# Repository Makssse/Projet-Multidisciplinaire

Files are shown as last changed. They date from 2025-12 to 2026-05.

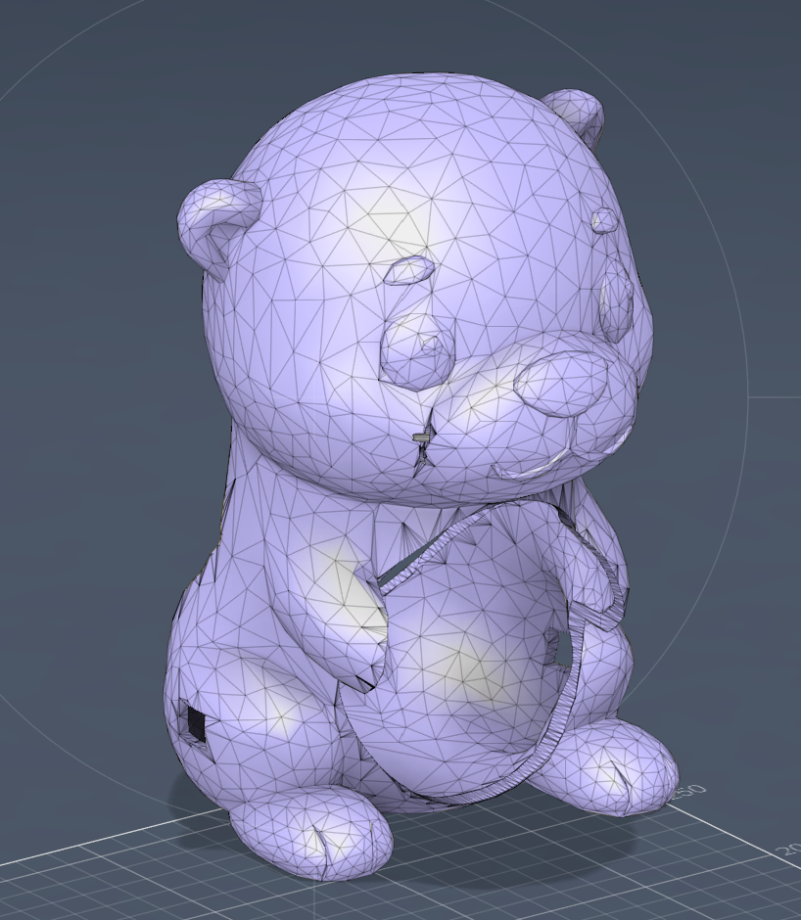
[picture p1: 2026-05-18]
impression_3d/Fichiers pour impression/Loutre VF.png

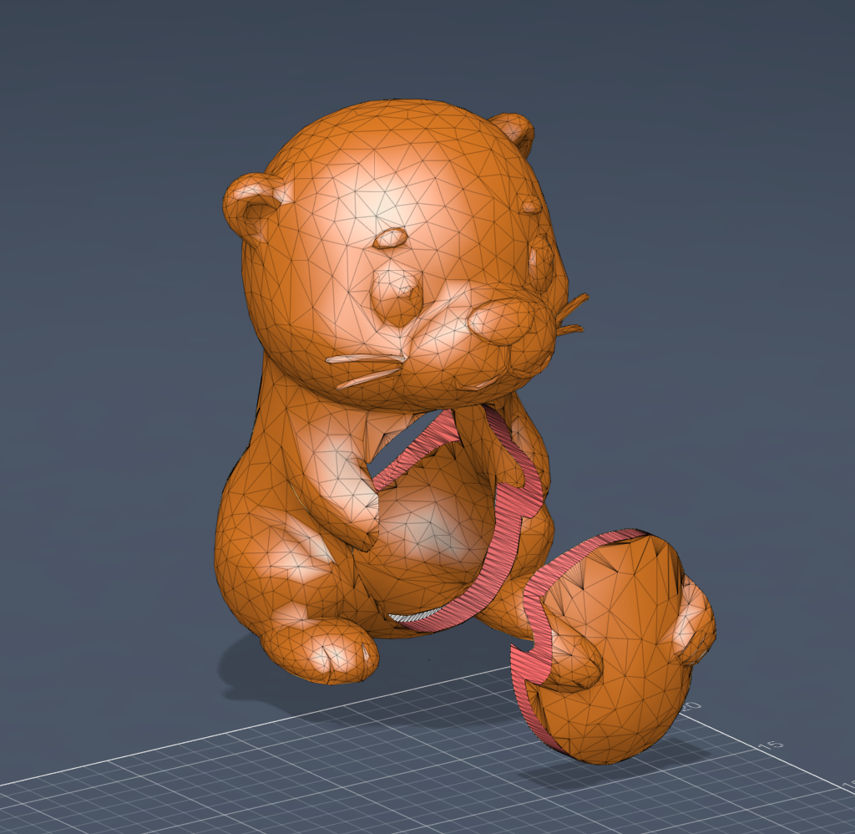
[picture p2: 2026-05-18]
impression_3d/Fichiers pour impression/Loutre et ventre.png

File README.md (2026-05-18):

# Projet-Multidisciplinaire
Nous sommes des étudiants en Génie Physique à l'INSA Toulouse et travaillons sur un projet de réseau de capteurs C02 pour des bâtiments publics (écoles, mairies...). Nous avons crée ce GitHub dans le but de rendre ce projet accessible à tous.tes, notamment aux non-intié.e.s qui souhaiteraient l'implémenter dans leurs locaux.

Vous pouvez y trouver : 
- le "Guide de fabrication" qui est un manuel de construction contenant tous les détails nécessaires à la fabrication des capteurs et à la mise en place du réseau. Ce manuel indique dans chaque section quand se servir des autres ressources du Github.
- le dossier "Home Assistant" qui contient tout les codes nécessaire à la création de l'interface utilisateur.
- le dossier "src" qui contient tout le code python et notament :
    - les codes à implémenter sur les pi pico (dossiers "code salle x")
    - le code pour tester son réseau ethernet dans le dossier "test_ethernet" (le protocole de test est disponible dans la section test ethernet du manuel de fabrication)
    - les codes de test pour chaque composante et capteurs dans le dossier "code test"
    - les autres code qui nous ont été utile dans le dossier "autre code"
- le dossier initialisation RP Pico qui contient le fichier d'initialisation de la Pi Pico. Vous trouverez le protocole dans le guide d'utilisation.
- le dossier "impression 3D" ou vous trouverez tous les fichiers nécessaire à l'impression de la coque 3D dans un fablab, les fichiers à imprimés étant dans le dossier "fichiers pour impression" : "LOUTRE_CREUSEE_VF" et  "LOUTRE_VENTRE_VF".
- le dossier "rendus INSA" avec touts les documents que nous avons du produire et rendre pour lors de ce projet à nos enseignant.es.

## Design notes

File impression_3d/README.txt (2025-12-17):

Mini Otter by AR3DP on Thingiverse: https://www.thingiverse.com/thing:7198225

Summary:
If you enjoy my designs and would like to support my work, or get a commercial license to sell prints of my models — you can join me on Patreon: 👉 https://www.patreon.com/cw/AR3DPI’ll be gradually adding colored profiles for the Mini Zoo collection on my Patreon.This model depicts a playful otter interpreted in the Mini Zoo style, featuring rounded shapes, soft transitions, and a friendly upright pose that emphasizes its curious and gentle demeanor. The low-poly treatment of the body and tail provides structure while maintaining the charm of a compact collectible.The Mini Otter embodies curiosity and playfulness, making it a lively addition to the Mini Zoo’s aquatic category. It complements models like the penguin and seal, representing an important balance between land and water creatures within the collection.Recommended material: PLA+ or PETG for smooth surfaces and durability. Use a medium brown for the body and a lighter cream tone for the chest and muzzle. A 0.16 mm layer height is ideal for capturing the subtle contouring of the face.A little message:Your support helps me keep creating and improving new designs every day. Don’t forget to follow, like, and favorite the models you enjoy, it truly helps and motivates me to keep exploring new ideas and sharing more creations. And please share photos of your printed versions, it’s always exciting to see how each person brings their own style and creativity to life! Thank you for being part of this journey!

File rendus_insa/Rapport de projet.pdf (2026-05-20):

# Rapport de projet

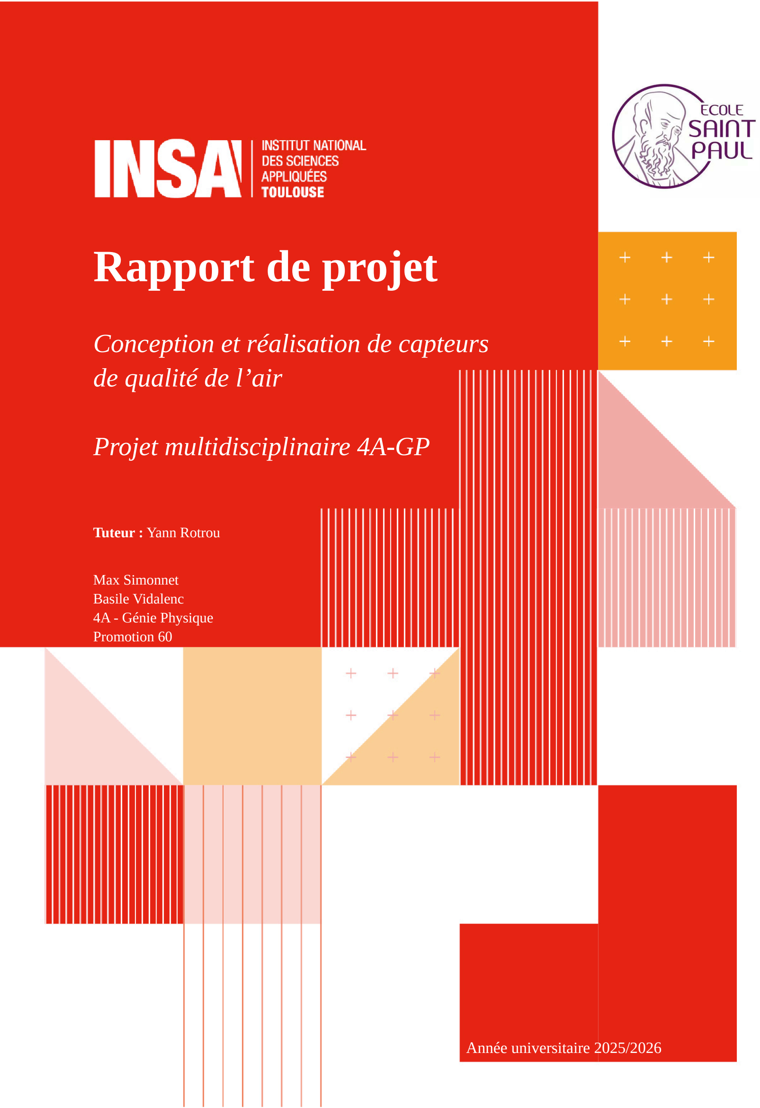
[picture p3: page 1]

## Conception et réalisation de capteurs de qualité de l’air

## Projet multidisciplinaire 4A-GP

Tuteur : Yann Rotrou

Max Simonnet
Basile Vidalenc
4A - Génie Physique
Promotion 60

Année universitaire 2025/2026

## 1. Résumé

Ce projet est un projet de conception et de réalisation d’un réseau de capteurs de qualité de l’air intérieur (QAI) pour un établissement scolaire. L’école Saint Paul, dans laquelle prend place notre projet, avait déjà réalisé une session d’auto-évaluation QAI avec des capteurs commerciaux. Elle n’a cependant pas retrouvé dans ces capteurs deux fonctionnalités qui lui sont nécessaires : l’affichage ludique d’un statut instantané et l’acquisition des données de façon permanente. De plus, ces capteurs présentent un coût élevé (120€ pièce pour un capteur NetAtmo).

Ainsi, dans notre projet, chaque capteur, placé dans un boîtier de mesure, mesure la qualité de l’air (CO2), la température, l’humidité relative et le volume sonore relatif et donne des indications en temps réel et permettant au enseignant.e.s de savoir quand il faut aérer la salle, et aux élèves d’être sensibilisé.e.s. L’acquisition des données se fait ensuite sur une centrale d’acquisition, permettant ainsi des analyses et la mise en place d’actions plus long terme.

## 2. Remerciements

Tout d’abord, un merci infini à notre tuteur, M. Yann Rotrou. Yann, tu as été une très belle rencontre tant sur le plan humain que sur le plan professionnel cette année. Tu as toujours été à l’écoute et bienveillant lorsque nous étions au point mort. Tu nous as fait confiance en nous laissant une grande autonomie, toujours partant pour chacune de nos idées sans jamais nous pressuriser tout en nous guidant sur les éventuelles difficultés que nous pouvions rencontrer. Un immense merci à toi pour ce projet et cette année !

Ensuite, nous tenions à remercier chaudement M. Jérémie Grisolia, dont l’expertise nous a fait gagner un temps précieux dans la recherche des composants, du protocole de communication adapté et de la bonne interface graphique. Jérémie, la porte de ton bureau était toujours ouverte quand nous avions des questions, des points de blocage, des erreurs… et le tout avec une gentillesse extrême. Merci à toi pour tout cela !

De même, un grand merci à Cathy avec qui nous avons conceptualisé et produit une première ébauche de PCB pour acquérir le signal du capteur. Merci à toi pour ta patience et ton absence de jugement sur nos compétences parfois douteuses en électronique.

Sur le plan organisationnel, nous remercions Lise Arnould, dont l’efficacité et la rapidité extrême nous ont permis d’aller en personne mettre en place le projet au sein même de l’école dans les meilleures conditions.

Un immense merci au Fablab de l’INSA et à ses bénévoles, qui ont passé des heures avec nous pour peaufiner nos design afin de les rendre imprimable en 3D dans les meilleures conditions.

Enfin, merci au CSN et notamment à Louis Chanouha, qui nous a ouvert un sous-réseau au GP.

Merci aussi à tout.es celleux qui ont pu nourrir ce projet en mettant à disposition en ligne des ressources Open Source. La majorité de notre code, notre design 3D, et toutes les connaissances que nous avons acquises : nous les devons à ces personnes. Nous espérons que notre projet pourra un jour inspirer ou aider quelqu’un à son tour.

## 3. Table des matières

## 4. Contexte

Ce projet s’inscrit dans notre 4ème année de formation à l’INSA Toulouse dans la spécialité Génie Physique. Nous sommes donc deux étudiants et notre tuteur Yann Rotrou est ingénieur en instrumentation chez Safran. Il est également impliqué dans la vie administrative et associative de l’école Saint Paul de Cesson en tant qu’administrateur OGEC (Organisme de Gestion des Ecoles Catholiques). A ce titre, il siège au Conseil d’Administration de l’école et participe donc aux décisions en terme de d’organisation, de finance et de fonctionnement de l’école. Pour l’école Saint Paul, ce projet fait suite à la campagne d’auto évaluation de 2024, et fait partie du plan d’action présenté dans son rapport. Il repose sur le constat qu’il n’existe pas de capteur commerciaux respectant le besoin d’un affichage ludique, d’une centralisation des données et d’un faible coût, correspondant aux capacités économique d’un établissement scolaire.

### 4.1 Contexte réglementaire

La conception et l’installation de capteurs de qualité de l’air intérieur dans un établissement scolaire doivent respecter plusieurs normes et recommandations, tant au niveau national qu’international. En France¹, la réglementation encadrant la qualité de l’air dans les établissements recevant du public (ERP) repose sur le Code de la santé publique et des recommandations du Ministère de la Transition écologique et de la Santé, qui définissent notamment des seuils d’exposition² pour les polluants atmosphériques (particules fines PM2,5 et PM10, dioxyde de carbone, composés organiques volatils, etc.), ainsi que pour le confort thermique et l’humidité intérieure. Concernant le bruit, les normes françaises (NF S31-080 et NF EN ISO 3382) fixent des limites d’exposition³ dans les espaces publics et scolaires afin de préserver l’audition et le confort des élèves et du personnel.

### 4.2 Contexte sanitaire

Au niveau international, l’Organisation mondiale de la Santé (OMS) fournit des recommandations visant à protéger la santé des enfants et des adolescents. L’OMS établit des valeurs guides pour les concentrations de polluants atmosphériques dans les espaces intérieurs, notamment :

- Particules fines (PM2,5) : concentration annuelle moyenne inférieure à 5 µg/m³.
- Particules fines (PM10) : concentration annuelle moyenne inférieure à 15 µg/m³.
- Dioxyde de carbone (CO₂) : concentration inférieure à 800 ppm pour garantir une ventilation adéquate et maintenir la concentration et la vigilance.
- Température intérieure : plage recommandée entre 18 et 22 °C pour assurer le confort thermique.
- Humidité relative : plage recommandée entre 30 % et 60 % pour prévenir les risques de moisissures et garantir le confort.

¹Arrêté du 27 décembre 2022 fixant les conditions de réalisation de la mesure à lecture directe de la concentration en dioxyde de carbone dans l’air intérieur au titre de l’évaluation annuelle des moyens d’aération (Légifrance)
²Tableau des normes Qualité de l’Air (ecologie.gouv.fr)
³Arrêté du 25 avril 2003 relatif à la limitation du bruit dans les établissements d’enseignement (Légifrance)

- Niveau sonore : niveau sonore inférieur à 35 dB(A) pour favoriser la concentration et l’apprentissage.

## 5. Présentation générale du projet

### 5.1 Le Github

Tout notre projet est disponible en open source sur Github. Vous pouvez y trouver tous les fichiers utilisé, les codes sources et un guide de fabrication et d’utilisation qui permet de refaire chez soi le réseau de capteurs. Tout notre code est donc disponible à cette adresse : https://github.com/Makssse/Projet-Multidisciplinaire

### 5.2 Contraintes

Pour réaliser ce projet nous nous sommes basé sur un cahier des charge fournit par notre tuteur. Il est résumé ci-dessous les principales contraintes et objectifs présent dans ce cahier.

### 5.2.1 Au niveau du boîtier de mesures

1. Chaque boîtier ludique doit admettre au minimum un capteur de taux de CO2 et un capteur de température.
2. Le capteur de taux de CO2 doit reposer sur la technologie NDIR.
3. L’aspect visuel du boîtier doit être ludique. Il pourra être discuté avec la directrice de l’établissement.
4. Le boîtier doit visuellement présenter un voyant vert lorsque le taux de CO2 est inférieur à 800ppm, orange lorsque le taux de CO2 dépasse le 800ppm, et rouge lorsque le taux dépasse 1500ppm. Cela permettra d’ouvrir la fenêtre quand besoin. En optionnel, ces seuils doivent pouvoir être modifiés sur la centrale d’acquisition, pour tous les capteurs.
5. La couleur doit être visible à quelques mètres, pour l’ensemble des élèves de la classe.
6. Les boîtiers doivent être alimentés sur le secteur, ou équipés de batteries ayant une autonomie supérieure à 6 mois.

### 5.2.2 Au niveau du système d’acquisition/gestion

7. Possibilité de définir des heures de présence (par défaut, identiques pour toutes les pièces, à l’échelle de la semaine. En option : configurable pour chaque pièce).
8. Sur les heures de présence, sauvegarde de toutes les grandeurs physiques mesurées toutes les 10 minutes, et enregistrement centralisé. Le matériel et le protocole de communication sont à discuter⁴.
9. Les boîtiers sont identifiables et on peut leur attribuer sur l’interface un nom facilement modifiable à la journée.
10. Afin de pouvoir maintenir ou remplacer le matériel, toutes les informations nécessaires sont fournies : plan des boîtiers, code source et description de l’installation de l’interface centrale.

⁴après discussions avec notre tuteur et l’école, l’idée d’un système filaire fut privilégiée

### 5.3 Description et fonctionnement final

Le système final (Figure 1) est donc composé de boîtiers d’acquisitions qui :
- Pilotent des LED qui changent de couleurs selon le niveau de CO2 (vert < 800ppm : orange < 1500ppm ; rouge > 1500ppm) en continue.
- Envoient des données toutes les 10min via Ethernet.

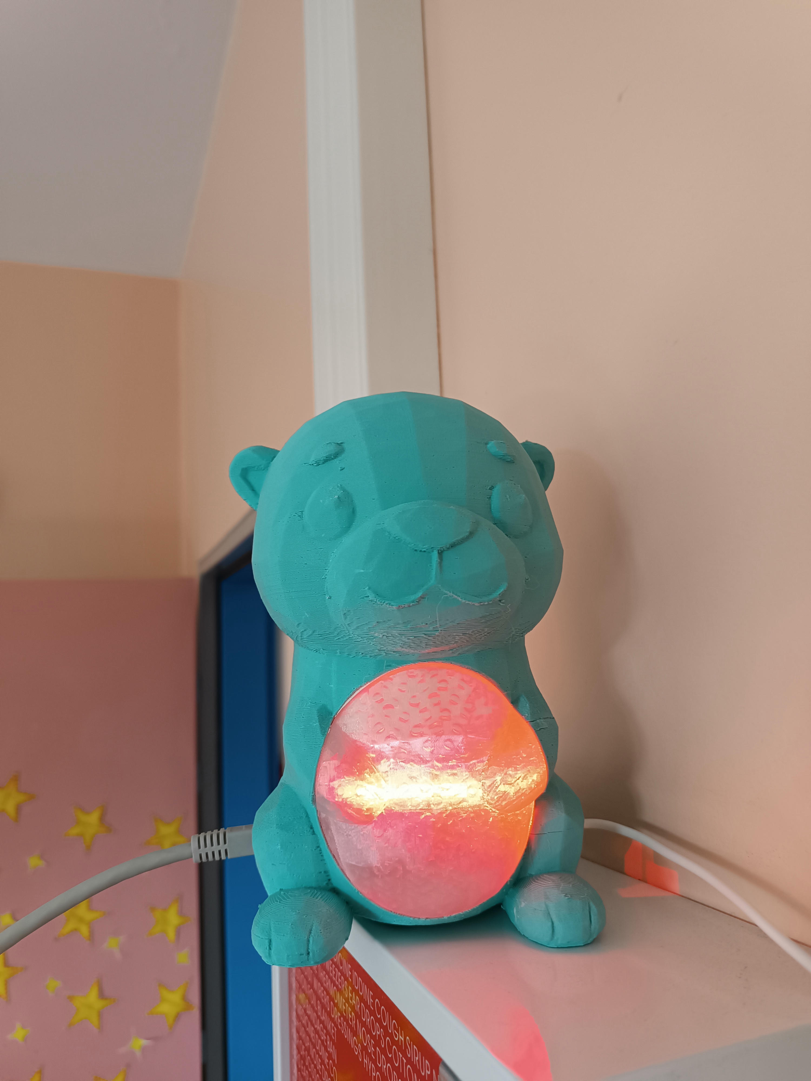
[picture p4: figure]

Fig. 1. – Photo de notre loutre en fonctionnement avec un taux de CO2>1500ppm.

Chaque boîtier de capteur est composé d’une coque imprimée en 3D, d’une Raspberry Pi Pico, d’un capteur Groove Loundness Sensor (en bas de la Figure 2), d’un capteur SCD 40 (petit boitier en haut de la Figure 2), de LED adressables et de toute la connectique nécessaire (shield Pi Pico, câble Ethernet et alimentation).

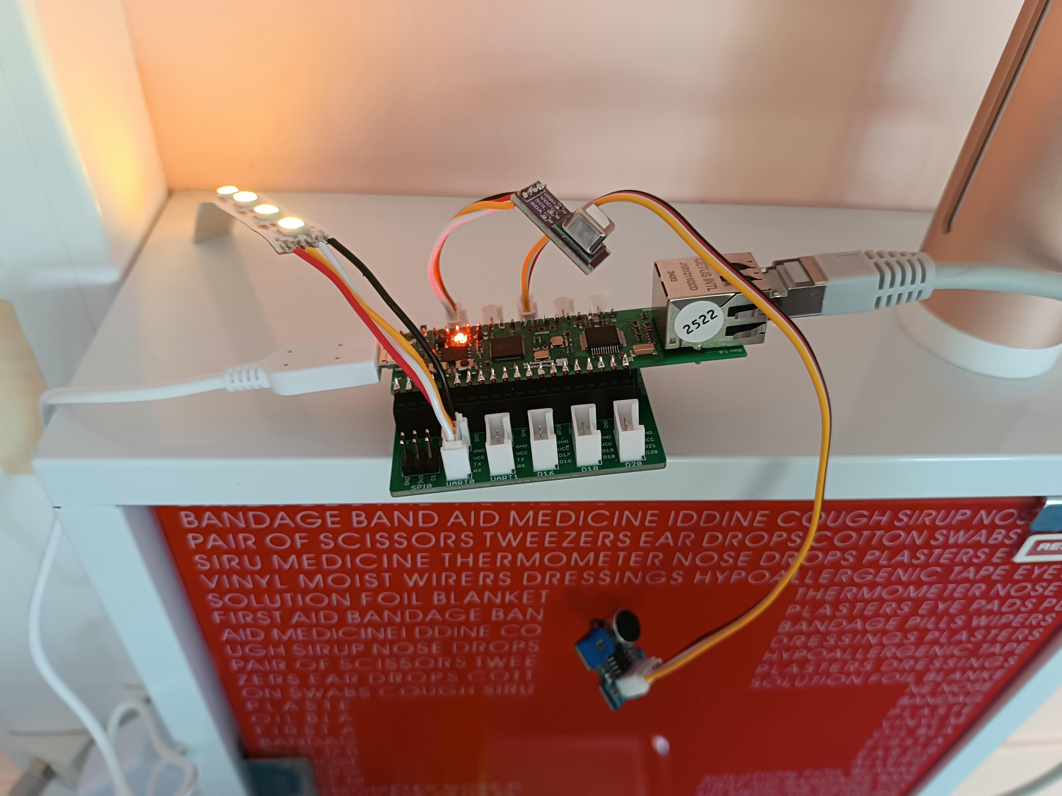
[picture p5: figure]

Fig. 2. – Photo du la Pi Pico et de ses composantes, destinés à aller dans la loutre de la Figure 1.

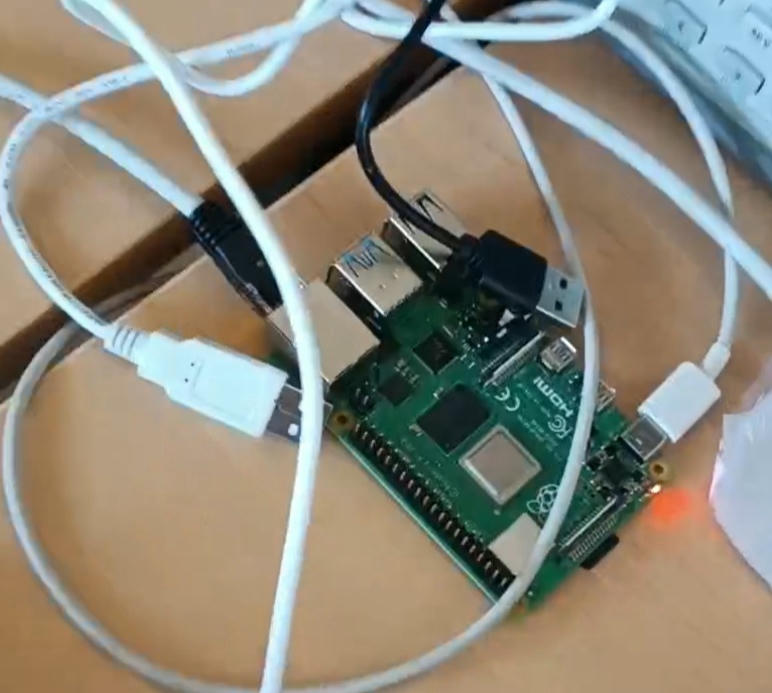
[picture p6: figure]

Fig. 3. – Photo de la Raspberry Pi 4, connecté à Ethernet.

Une Raspberry Pi 4 (Figure 3) reçoit ensuite toute la donnée Ethernet et permet d’afficher sur un ordinateur relié au réseau une interface utilisateur Home Assistant qui permet :
- De voir en direct et sur différentes échelles de temps les données pour chaque capteur.
- D’arrêter ou de mettre en marche les capteurs de manière collective ou individuelle, et de manière manuelle ou automatique (en définissant des heures/jours de présence).
- D’effectuer des re-calibrations pour la température et le taux de CO2 pour chaque capteur.
- D’envoyer des rapports automatiques via Telegram.
- De calculer et d’afficher l’indice ICONE (un indice sur la QAI) pour chaque salle en pouvant choisir l’échelle de temps sur laquelle l’indice est calculé.

Nous allons revenir dans la partie suivante plus en détail sur le fonctionnement global, sur le rôle de chaque composante du projet et sur le travail effectué.

## 6. Travail réalisé

### 6.1 Choix des composants

Nous avons choisi les composants en début de projet afin qu’ils correspondent au cahier des charges tout particulièrement sur les aspects :
- ludique (pour le boîtier de mesure qui sera dans les salles)
- d’accessibilité et de reproductibilité (pour que tout un chacun puisse recréer le projet chez lui)
- de conformité aux normes de mesure CO2 (technologie NDIR)

Pour plus d’informations sur ce qui a motivé nos choix, se référer à la ScoreCard présente en Annexe (Chapitre 8.1).

### 6.1.1 Le capteur de CO2 : SCD40

Le SCD40 de chez Sensirion est un capteur de CO2, Température et Humidité relative. Il utilise la technologie NDIR pour la mesure de CO2, qui est la technologie fixée par la norme française pour la mesure de CO2 dans les écoles.

La communication se fait via I2C. Le capteur possède 2 pins d’alimentation (V+ et GND) ainsi qu’une pin SDA pour les données et une pin SCL pour l’horloge. Sensirion a développé une bibliothèque Python que nous avons utilisé pour communiquer avec notre capteur et implémenter les fonctions utiles (plus d’info au Chapitre 6.4.1).

### 6.1.2 Le microcontrôleur : Raspberry Pi Pico W5500-ETH

Afin d’être parfaitement autonome dans le boîtier de capteur, il est nécessaire de se doter d’un microcontrôleur qui aura pour rôle de communiquer avec les différents modules que nous y branchons : le SCD40 (CO2), le Loudness Sensor (bruit), les LEDs (indication visuelle) et l’Ethernet.
Pour ce faire, nous avons choisi la Raspberry Pi Pico-W5500-ETH, qui rajoute un module Ethernet fixe à la Pi Pico de base. Ce microcontrôleur dispose des caractéristiques suffisantes à la mise en place de notre projet en terme de mémoire (264kB SRAM, 2MB Flash), de capacité de calcul (133MHz Dual-core) et de communication puisqu’il dispose de Pins I2C, digitaux (I/
O) et analogues.

### 6.1.3 La centrale d’acquisition : Raspberry Pi 4B+

Le choix de la centrale a été fait en même temps que le choix du logiciel pour l’acquisition et le traitement de données, et l’interface graphique. Nous avons décidé de partir sur Home Assistant OS puisque l’école fonctionnait déjà dessus avec une Raspberry Pi 4B+ pour ses capteurs commerciaux. Ainsi, étant déjà lancés dans la suite Raspberry, nous avons décidé de choisir une Pi4B+ également. La Raspberry Pi 4 est compatible avec Home Assistant et possède des caractéristiques suffisantes en terme de stockage (32GB) et de RAM (2GB minimum).

### 6.1.4 L’indication visuelle : les LEDs adressables

Les LEDs adressables sont un bon outil pour maîtriser l’information visuelle que l’ont veut donner. Ces LEDs peuvent être adressées puis contrôlées individuellement via les Pins DT (DATA) et CLK (CLOCK), en étant alimentées via les Pins V+ (tension d’alimentation) et GND (masse) (plus d’info au Chapitre 6.4.1).

### 6.2 La coque 3D

Pour réaliser la forme du boîtier de capteur qui sera présent dans les salles de classe, nous nous sommes basés sur ce modèle⁵ (https://www.thingiverse.com/thing:7198225) de loutre, crée par AR3DP.

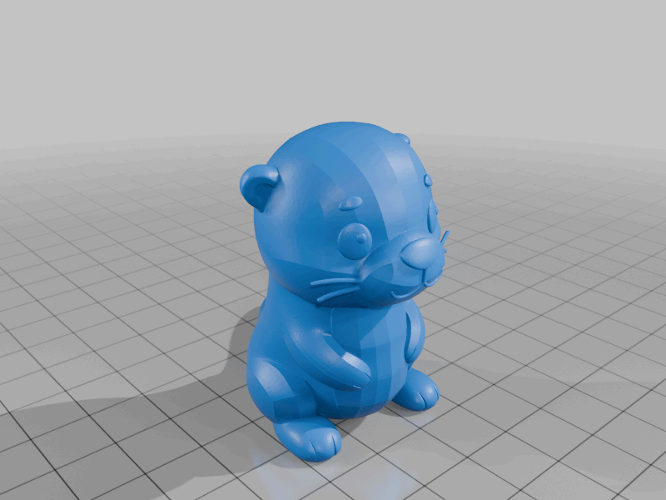
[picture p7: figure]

Fig. 4. – Modèle initial du boîtier (créateur : AR3DP)

Ce modèle est sous licence CC BY-NC 4.0 qui nous permet de le modifier et de le partager gratuitement, en citant l’auteur.

A l’aide de l’outil Meshmixer, nous avons creusé l’intérieur de la loutre pour ensuite extruder l’avant et l’arrière sur Fusion 360. Le trou à l’arrière sert à placer le capteur dans la loutre, et celui à l’avant à placer un ventre transparent qui permet de diffuser la lumière produite par les LEDs. Enfin, 2 trous rectangulaires ont été placés sur les côtés de la loutre afin de faire passer les câbles USB et Ethernet, nécessaires respectivement à l’alimentation et à la connexion au réseau. L’impression en fabrication additive a été faite au FabLab de l’INSA, en PETG bleu cyan pour la loutre et en PETG transparent pour le ventre.

⁵https://www.thingiverse.com/thing:7198225

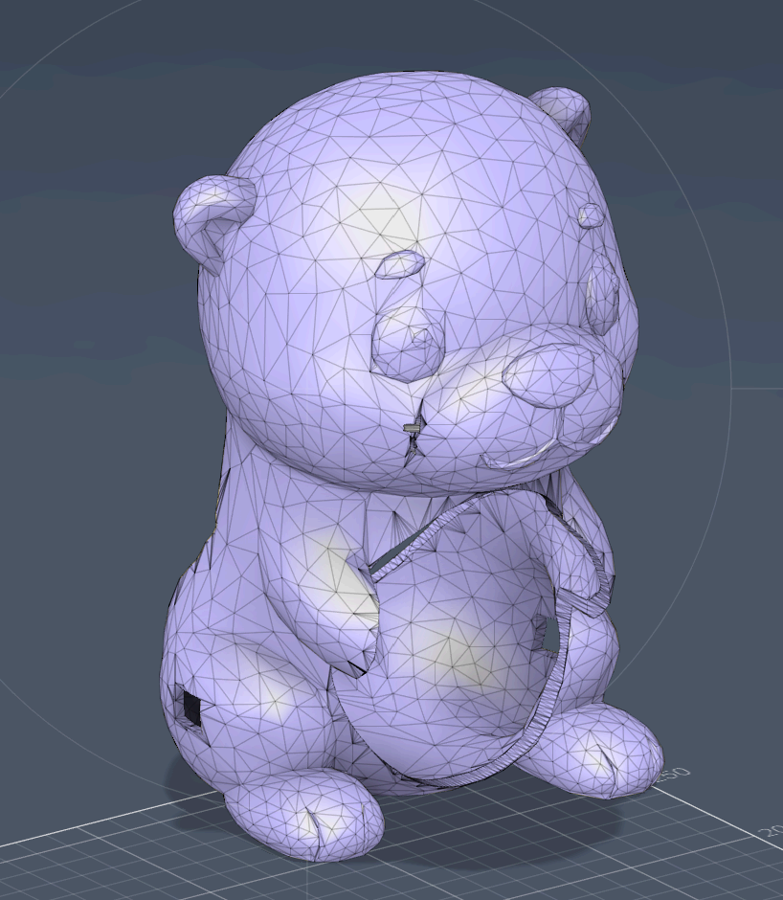
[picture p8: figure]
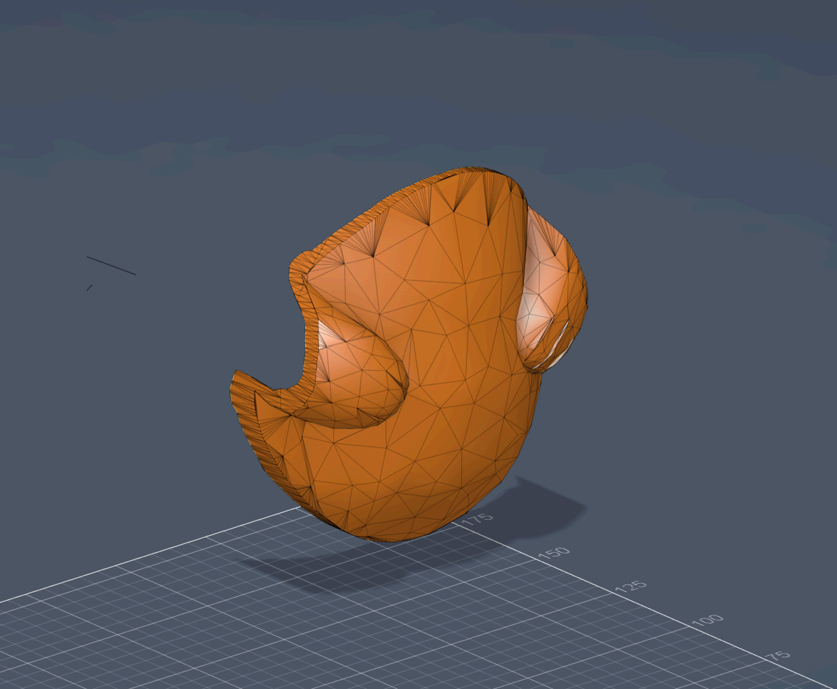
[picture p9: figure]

Fig. 5. – Loutre et ventre, fichier prêt pour impression (.stl)

### 6.3 La mise en place réseau

### 6.3.1 Communication MQTT

Pour assurer la communication entre les boîtiers de capteurs et la centrale d’acquisition, nous avons choisi le protocole MQTT (Message Queuing Telemetry Transport). Ce protocole repose sur un modèle « publish/subscribe » : chaque Pi Pico publie ses données sur un « topic » (un canal de communication identifié par une chaîne de caractères), et la Raspberry Pi 4 qui fait tourner Home Assistant s’abonne à ces topics pour récupérer les données en temps réel. Un broker Mosquitto, installé sur la Pi 4, joue le rôle d’intermédiaire central et redistribue chaque message à tous les abonnés concernés.

Nous avons fait le choix d’implémenter nous-mêmes la couche MQTT dans notre bibliothèque lib_mqtt.py plutôt que d’en utiliser une existante, afin de garder un code léger et adapté aux contraintes mémoire de la Pi Pico. Concrètement, à chaque démarrage, la Pi Pico établit une connexion TCP avec le broker en lui envoyant un paquet CONNECT contenant son identifiant, ses identifiants de connexion et un testament (will_topic()). Ce dernier permet au broker de publier automatiquement un message offline si le capteur venait à se déconnecter brutalement, ce qui permet à Home Assistant de détecter une panne.

Une fois connectée, la Pi Pico fonctionne dans les deux sens. D’un côté, elle publie toutes les 10 minutes ses mesures (CO₂, température, humidité, bruit) au format JSON sur son topic dédié. De l’autre, elle est abonnée à un topic de commande "/set_status" sur lequel Home Assistant peut envoyer des ordres : allumer ou éteindre le système, modifier l’offset de température, changer les seuils d’alerte CO₂, ou encore forcer une recalibration du SCD40. Ces messages entrants sont traités par la fonction reception_message() du main, qui est une fonction de rappel (callback) et s’exécute automatiquement dès qu’un message arrive. En effet, check_msg() ne déclenche automatiquement reception_message() que lorsque qu’elle détecte un message, afin de ne jamais bloquer le programme.

### 6.3.2 Tests sur l’INSA

Avec l’aide du CSN, nous avons mis en place un sous-réseau de test en salle d’instrumentation
2.15. Ce sous-réseau nous a permis de mimer un réseau local régit par une box, ce qui se rapproche le plus de l’architecture réseau de l’école (peu de hiérarchie réseau/sous-réseau, ce qui facilite la communication entre ports). Ce sous-réseau contenait 4 ports Ethernet reliés entre eux et permettant de brancher :
- 1 Raspberry Pi 4 (centrale d’acquisition/Execution de Home Assistant),
- 1 PC (accès à Home Assistant)
- 2 Raspberry Pi Pico (mesure/indication visuelle/envoi de données à la centrale)

A l’aide de ce sous-réseau nous avons pu :
- créer l’interface utilisateur sur Home Assistant et d’implémenter des codes .yaml correspondant aux exigences de l’école via le PC (voir Chapitre 6.5.1)
- vérifier la robustesse de notre couche MQTT (créée par un code python) : envoi et réception de message sur la Pi Pico et sur Home Assistant.
- identifier les points critiques qui pourraient poser problème lors de la mise en place à l’école :
- l’IP du Broker MQTT (i.e. de la Pi 4), essentielle à connaître et à indiquer dans le main.py des Pico afin de pouvoir communiquer
- l’IP de la passerelle, du masque de sous-réseau et du DNS, à indiquer dans lib_mqtt.py

### 6.3.3 Mise en place à l’école

Lors de la mise en place du réseau, basée sur la « Feuille de route mise en place du réseau » présente sur notre GitHub, nous avons suivi les étapes suivantes afin de tester la communication MQTT :
- récupération des IPs utiles (passerelle, masque de sous-réseau, DNS) et implémentation dans notre code
- fixation de l’IP de la Pi 4 (donc du Broker MQTT) et implémentation dans notre code
- connexion au Home Assistant via un PC connecté au réseau
- test de tous les ports Ethernets de l’école et vérification qu’ils sont sur le même réseau
- test final en faisant tourner notre code

Mis à part un problème de temps d’attente de connexion au réseau pour les Pi Pico dans certaines salles (voir Chapitre 7.2.2), la mise en place s’est déroulée sans accrocs.

### 6.4 Le code de la Pi Pico

Nous allons dans cette section aborder le code implémenté sur la Raspberry Pi Pico que nous avons créé et testé sur l’environnement VS Code. Ce code permet 2 choses :
- De fonctionner de manière autonome et d’indiquer grâce à la bande LED le taux de CO2.
- De recevoir et d’envoyer des messages via MQTT.

Nous n’allons pas aborder tous les codes réalisés, il y a notamment en plus sur le Github des codes de tests des différents composants et du réseau Ethernet. Dans cette section nous allons dans une première partie revenir sur les différentes librairies que nous avons créées, puis sur le code principal dans une seconde partie.

### 6.4.1 Nos différentes bibliothèques

- lib_Led.py :

Cette bibliothèque se base sur une bibliothèque récupérée depuis un Github de pilotage python des LED WS2812B. On y retrouve la fonction config_led() qui permet d’initialiser les LEDs en passant en argument le nombre de LED, l’intensité voulue et les pins sur lesquelles elles sont connectées. La fonction indicateur_visuel() qui permet de changer la couleur du bandeau LED en passant en argument le taux actuel de CO2. La dernière fonction est piloter_led() qui permet d’allumer complètement (lumière blanche) ou d’éteindre le bandeau LED.

- lib_son.py :

Cette librairie permet d’utiliser le Grouve Loundness Sensor.
On y trouve la fonction config_port_son() qui initialise le capteur en passant en argument la pin sur laquelle il est connecté. La deuxième fonction est niveau_sonore() qui renvoie une valeur brute du niveau sonore comprise entre 0 et 65535.
- lib_scd4x.py :

Cette bibliothèque se base sur une bibliothèque récupérée depuis le Github officiel du SCD40 ainsi que sur une bibliothèque Adafruit. Elle permet de contrôler le SCD40.
On y retrouve la fonction config_port_scd() qui permet de définir les pins SDA et SCL. La fonction obtenir_donnees() qui renvoie le taux de CO2, la température et l’humidité relative. Enfin deux fonctions permettent de modifier les paramètres de fonctionnement du SCD40. change_parametres() permet de mettre à jour l’offset de température (que l’on doit corriger pour prendre en compte l’échauffement du capteur) et l’altitude de fonctionnement. recalibration() permet de forcer une calibration sur un niveau de CO2 connu. Sinon le SCD40 effectue une calibration automatique toutes les semaines en se basant sur les valeurs les plus basses rencontrées.
- lib_mqtt.py :

Cette bibliothèque contient la class MQTTClient que l’on doit initialiser en donnant les informations de notre broker (ici relatives à la Pi 4).
On y retrouve la fonction connecter_ethernet() qui permet de configurer la connexion Ethernet (SPI et matériel). La fonction subscribe() permet de s’abonner à un sujet MQTT. La fonction check_msg() permet de vérifier si un message a été publié sur le sujet MQTT et publier() permet d’envoyer un message sur un sujet MQTT.
- lib_IP_MAC.py :

Cette librairie contient la fonction connect_ethernet() qui met à jour la configuration (SPI et matériel) et renvoie l’adresse IP et MAC de la Pi Pico qui exécute le code. Elle est utile car la communication MQTT nécessite de connaître ces adresses. Cette fonction permet donc d’automatiser la récupération de ces adresses et d’utiliser le main.py avec n’importe quelle Pi Pico.

### 6.4.2 Le main

Nous allons maintenant aborder le fonctionnement global du main, en revenant sur ses différentes fonctions, puis sur son corps.

- reception_message() :

Cette fonction de rappel s’exécute automatiquement dès qu’un message MQTT est reçu sur un sujet auquel la Pi Pico est abonnée. Elle décode le message pour intercepter les ordres provenant de Home Assistant. Elle gère l’allumage ou la mise en pause du système (ordres ON et OFF) via la variable globale global systeme_actif, et permet également de modifier dynamiquement à distance l’offset de température, les seuils d’alerte CO2 ou de forcer une recalibration du capteur SCD40.

- tache_leds_et_capteur() :

Cette tâche asynchrone s’exécute en continu toutes les 10 minutes. Son rôle principal est de « nourrir » le chien de garde (Watchdog Timer) pour prouver que le système n’est pas bloqué, puis de récupérer les mesures physiques (taux de CO_2, température, humidité et niveau sonore) afin de mettre à jour le dictionnaire global donnees_actuelles. Si le système est actif, elle ajuste en temps réel la couleur du bandeau LED en fonction des seuils de CO2 définis. Si le système est mis en pause, elle s’assure de l’extinction physique des LEDs.

- tache_mqtt() :

Cette seconde tâche asynchrone gère la communication réseau avec le broker MQTT. Elle configure d’abord la fonction de réception des messages, puis s’assure en boucle de l’état de la connexion. En cas de déconnexion, elle reconnecte le client, s’abonne au sujet de commande "/set_status" et publie son état de disponibilité ("online"). Lorsque la connexion est établie, elle vérifie l’arrivée de nouveaux messages et publie régulièrement (toutes les 10 minutes par défaut) les données des capteurs au format .json, à condition que le système soit actif.

- main() :

Il s’agit de la fonction principale et du point d’entrée du programme. Elle commence par initialiser la sécurité du système via le chien de garde wdt() configuré sur un délai de 8 secondes. Elle configure ensuite l’ensemble du matériel (bandeau LED, capteur sonore et capteur SCD4x avec une réinitialisation forcée de sa mesure périodique). Après avoir initialisé la connexion Ethernet et le client MQTT, elle orchestre et lance simultanément les deux tâches asynchrones (tache_leds_et_capteur() et tache_mqtt()) grâce au moteur uasyncio.gather.

### 6.5 L’interface utilisateur

### 6.5.1 Fonctionnement Home Assistant

Nous avons dans ce projet configuré notre Home Assistant sur une Raspberry Pi 4B+ de l’INSA. Nous avons ensuite reconfiguré en environnement similaire à l’école Saint Paul. L’école disposait déjà d’une Raspberry 4 avec HA installé, nous avons donc dû configuré la connexion MQTT. Puis en copiant les codes sources de notre environnement INSA sur celui de l’école. Ces différents fichiers où est le code sont :

- configuration.yaml :
Ce fichier contient tout les capteurs qui vont permettre de recevoir et de traiter les données envoyées par la Pi Pico. Chaque capteur est associé à un « sujet », qui est un canal MQTT. Quand HA reçoit les données en .json, il les reçoit pour un sujet et il peut donc associer à un indicateur. Ce fichier contient également tous les éléments qui seront présents sur le tableau de bord. Ce sont « les entités », qui sont des objets avec une identité et des attributs comme un nom, une unité et des valeurs min et max par exemple.
- Le tableau de bord :
Le tableau de bord est l’endroit où sont encodés tous les attributs de nos indicateurs (taille, couleur, titre, …). Pour chaque indicateur, on associe une entité, l’indicateur avec le nom « CO2 salle 1 » sera donc connecté au taux de CO2 réel qui a pour entité « CO2_salle_1 » reçu sur le sujet de conversation MQTT « topic_CO2_salle_1 ».
- automation.yaml :
Ce fichier contient toutes les automations qui sont des actions effectuées automatiquement sous certaines conditions. La principale automation de notre interface est d’allumer et d’éteindre tous les capteurs selon des heures de fonctionnement définies, dans notre cas donc d’allumer tout les capteurs entre 8h et 21h.
- script.yaml :
Le fichier script lui permet aussi d’effectuer d’autres types d’actions, par exemple des actions MQTT. Pour nous, le fichier script contient des scripts pour envoyer certains types de messages MQTT.

Une fois tous ces codes collés dans le Home Assistant de l’école et après vérification que la compilation a réussi, nous avons pu effectuer nos premiers tests.

### 6.5.2 Interface finale

La Figure 6 et 7 sont des captures d’écran de notre tableau de bord, qui est donc l’espace depuis lequel la gestionnaire de l’école va utiliser les données des capteurs.

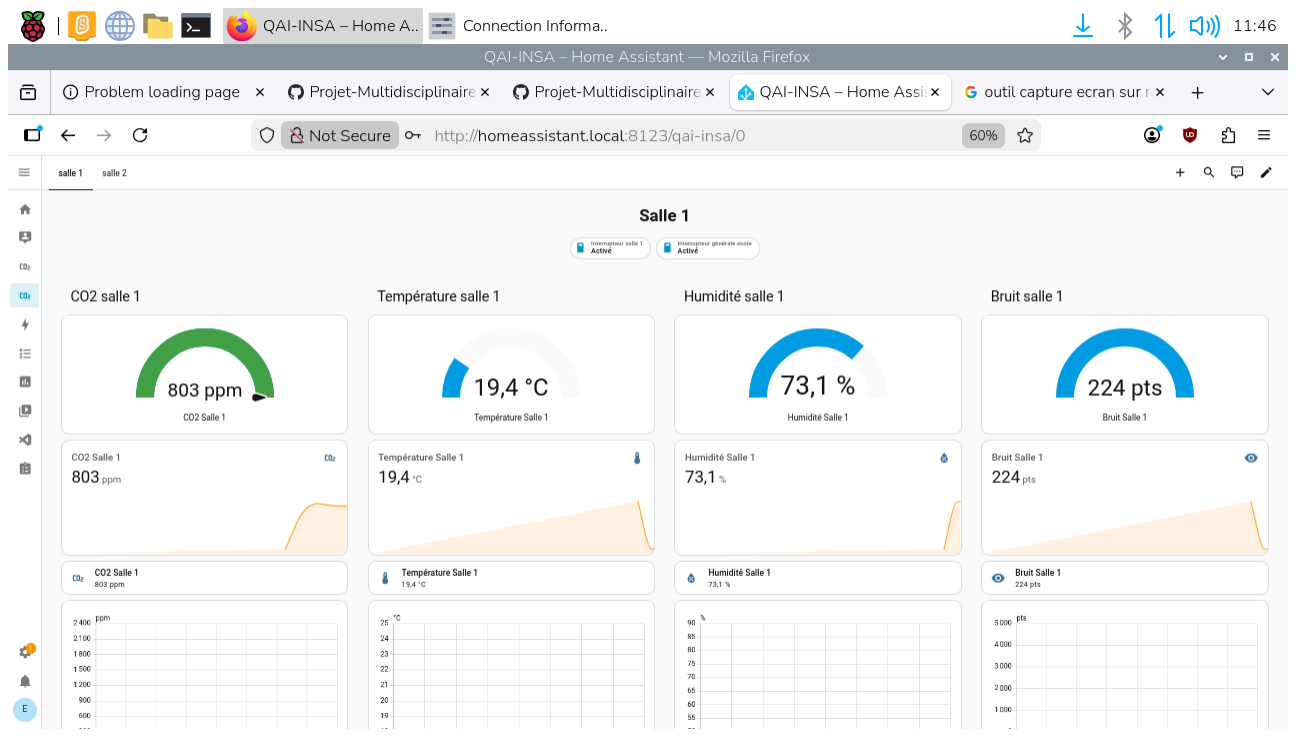
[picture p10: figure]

Fig. 6. – Capture d'écran du tableau de bord des capteurs.

Nous allons revenir sur les différents éléments qui composent ce tableau de bord et ce qu’il est possible de faire :

- Les salles :

En haut de la Figure 6, on voit qu’il est possible de choisir la salle que l’on veut visualiser. Toute l’interface est donc accessible pour chaque salle, donc pour chaque boîtier. Au moment où nous avons réalisé l’installation à l’école, deux capteurs étaient présent.

- Les indicateurs :

Sur la Figure 6 on peut voir les différents indicateurs disponibles pour chaque grandeur. On a notamment la jauge en temps réel, l’évolution à court terme, les statistiques de long terme et l’état (disponible ou indisponible).

- Les interrupteurs :

En haut de la Figure 6 on peut voir des interrupteurs. Il y a pour chaque salle un interrupteur spécifique. L’interrupteur interrompt l’envoi de la donnée et l’allumage des LEDs. Il y a aussi un interrupteur global qui contrôle en même temps tous les interrupteurs, et qui permet donc d’éteindre/allumer toutes les salles.

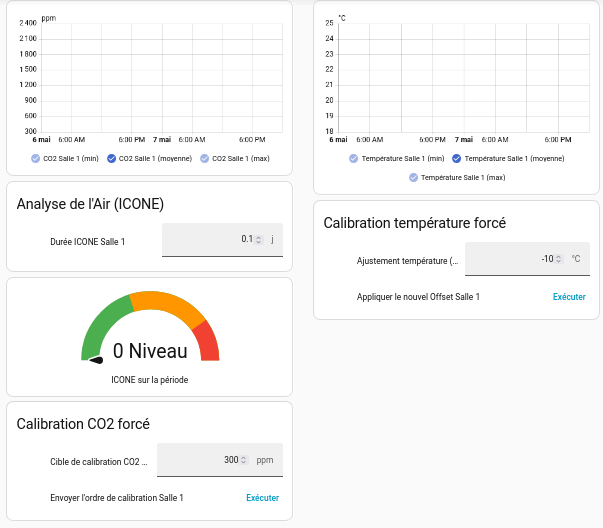
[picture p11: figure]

Fig. 7. – Capture d'écran du tableau de bord des capteurs (en dessous de ce qui est visible sur la Figure 5).

- L’indice ICONE :

L’indice ICONE est un indicateur réglementaire utilisé pour évaluer le niveau de confinement de l’air intérieur dans les écoles et les lieux publiques en général. Il varie de 0 (confinement nul) à 5 (confinement extrême) comme ceci :

N = 8.3 ⋅ log10

(1 + f1 + 3f2

)

Où :

- ‣ N est la valeur brute de l’indice (arrondie à l’entier le plus proche pour obtenir la note ICONE finale de 0 à 5), plus il est faible, plus la QAI est bonne.
- f1
représente la fraction de temps où la concentration en CO2
est comprise entre 800 ppm et 1500 ppm.
- f2
représente la fraction de temps où la concentration en CO2
dépasse 1500 ppm.
- Les commandes :

Parmi les commandes qui sont visibles sur la figure on a d’abord le temps sur lequel sera calculé l’indice ICONE. Ce qui permet aussi bien de calculer une note sur la dernière heure que le dernier mois. On a également une commande pour forcer la calibration du SCD40 à un certain seuil de CO2 connu. On a finalement une commande pour appliquer un offset de température au SCD40 (la mesure de la température peut dériver à cause de l’échauffement dû au fonctionnement). Toutes ces commandes fonctionnent sur le principe d’envoi de messages MQTT.

## 7. Bilan

### 7.1 Nos résultats finaux

Au final nous avons pu livrer à l’école Saint Paul un réseau de 2 capteurs fonctionnels avec une interface utilisateur facile à prendre en main. L’école pourrait avoir besoin d’un réseau allant jusqu’à 17 capteurs mais le but est aussi de jauger les besoins avant d’en fabriquer de nouveaux.

Le point positif de ce réseau est que le coût unitaire d’un capteur est moins cher que dans le commerce (< 80euro) pour une norme similaire (technologie NDIR), une plus grande réparabilité (changement d’un composant contre changement de tout le capteur, voir Chapitre 8.1). Un autre avantage est la plus grande flexibilité et le nombre important de fonctions :

- Il y a un capteur de bruit.
- Tout le projet est modifiable sous condition de se plonger dans le code HA et python.
- Il y a un aspect « paramétrage pédagogique » : dans d’autres établissements, les capteurs tout le temps en alarme, et les enseignant.es et élèves ont finit par les ignorer. Nos capteur peuvent changer de seuil d’alarme.
- Il y a une centralisation des données pour prendre des actions plus long terme (consignes générales d’ouvertures des fenêtres, ouverture permanente d’au moins une porte, dimensionnement de la VMC,…)
- Le projet à un aspect ludique et les capteurs plaisent aux enfants.

Le principal point de vigilance est que le réseau est utilisable par des non-initiés en informatique mais en cas de panne, bugs ou si l’on veut modifier quelque chose, cela nécessite des bases en minimales en informatique.

### 7.2 Retour d’expérience et gestion du projet

### 7.2.1 Organisation

Pour mener à bien ce projet nous avons dû nous organiser. Nous avons d’abord fait des visioconférences régulières avec notre tuteur, toutes les deux semaines environ. Durant ces visios nous le tenions au courant de l’avancement du projet, nous discutions et validions les choix à faire (choix des composants ou du langage de code ou design du capteur par exemple) et nous lui posions également des questions, principalement sur l’environnement de l’école, et parfois technique (sur le fonctionnement de HA par exemple). Nous avons également communiqué par WhatsApp pour les informations plus en continue et l’organisation des visios et des déplacements. Concernant les déplacements, nous avons vu Yann une première fois à Toulouse en milieu d’année puis nous avons effectué un déplacement à l’école Saint Paul début mai pour mettre en place le réseau. Nous avons pour ce déplacement préparé en amont une feuille de route avec un emploi du temps de la journée, un tableau avec le matériel nécessaire et une liste des problèmes potentiels. Ce déplacement s’est très bien déroulé, nous avons pu découvrir l’école, mettre en place le réseau. Nous avons également pu expliquer et aider la gestionnaire et Yann à prendre l’outil en main, de sorte qu’ils soient le plus possible autonomes.

### 7.2.2 Difficultés rencontrées

Une première difficulté a été rencontrée au début du projet. Il nous a semblé cohérent financièrement et pédagogiquement pour nous de concevoir les PCBs qui permettraient de communiquer avec le SCD40. Avec l’aide de Catherine Crouzet nous avons designé et produit un exemplaire qui n’a malheureusement pas marché après une batterie de tests (notamment réalisés avec Jérémie Grisolia). Nous avons donc finalement commandé notre SCD40 directement sur PCB, mais cela nous a permis d’aborder certains savoirs-faire en micro-soudure et en KiCad avant les cours du second semestre.

Une autre difficulté est arrivée lors de la mise en place du réseau à l’école. En effet, nous avons fait face à des problèmes réseau et nous avons debugger notre code pendant 2 à 3 heures, ligne par ligne. Il nous manquait à certains endroits de notre code des temps d’attente. Cela nous a ralenti et mis en retard sur le planning de la journée mais ne nous a pas empêché de finir l’installation de nos capteurs.

Finalement ce projet nécessitait en grande partie des connaissances sur des sujets que nous n’avions jamais abordés en cours. Notamment le réseau Ethernet, la conception 3D et l’instrumentation sur micro-contrôleur. Nous comptons cela comme une difficulté dans le sens où prendre en main certaines notions nous a demandé du temps. La mise en place d’un sous-réseau au GP nous a par exemple demandé beaucoup plus de temps que prévu car nous découvrions les contraintes d’Ethernet au fur et à mesure et nous avons dû faire de nombreux aller-retour de mails avec le CSN.

### 7.2.3 Apprentissages

Ce projet nous as beaucoup appris. D’abord sur le plan théorique. Nous avons découvert de nombreux domaines, notions, fonctions python et beaucoup de choses sur la suite Raspberry. Nous sommes satisfaits de ces apprentissages dans le sens ou nous sentons qu’ils pourrons être ré-utilisés dans d’autres contextes. La suite Raspberry est en effet utilisé dans des domaines très variés, le code python aussi, et les réseaux Ethernet également.

Sur le plan de l’organisation et de la communication nous avons aussi mené ce projet dans une autonomie assez grande, tout en communiquant avec des acteur.ice.s assez varié.e.s. Que ce soit à l’INSA, avec l’école et notre tuteur ou entre nous.

Et c’est peut être ici que ce projet nous a le plus appris : à travailler à plusieurs. Souvent des après-midi entières, nous avons fonctionné toujours avec l’autre, toujours dans la communication, l’entraide et le soutien. Ce projet aura été une grande source d’apprentissage sur le plan humain et relationnel. Nous pouvons noter la progression que nous avons réalisée au niveau de la gestion du stress, de l’organisation de planning à deux sur une semaine/un mois/un an, le partage de connaissances ou encore le partage des tâches.

### 7.3 Perspectives et suites

Pour finir ce projet il nous reste encore certaines choses à faire. Nous devons finaliser le Github et le manuel de fabrication. Aussi nous devrons probablement assurer un travail de suivi avec l’école au cas où le réseau rencontrerait des problèmes complexes.

Pour ce qui est des perspectives futures, nous espérons que ce projet pourra servir à d’autres, pour tout ou partie. Notamment aux écoles car nous avons vu au cours de ce projet qu’il y a une réelle problématique de qualité d’air en classe. Ce projet propose en effet un outil pour repenser la qualité de l’air lors de l’enseignement. Nous pouvons penser aussi peut être aux salles de sport, aux lieux accueillant du public ou même à l’INSA !

## 8. Annexes

# ScoreCard — Selection des composants

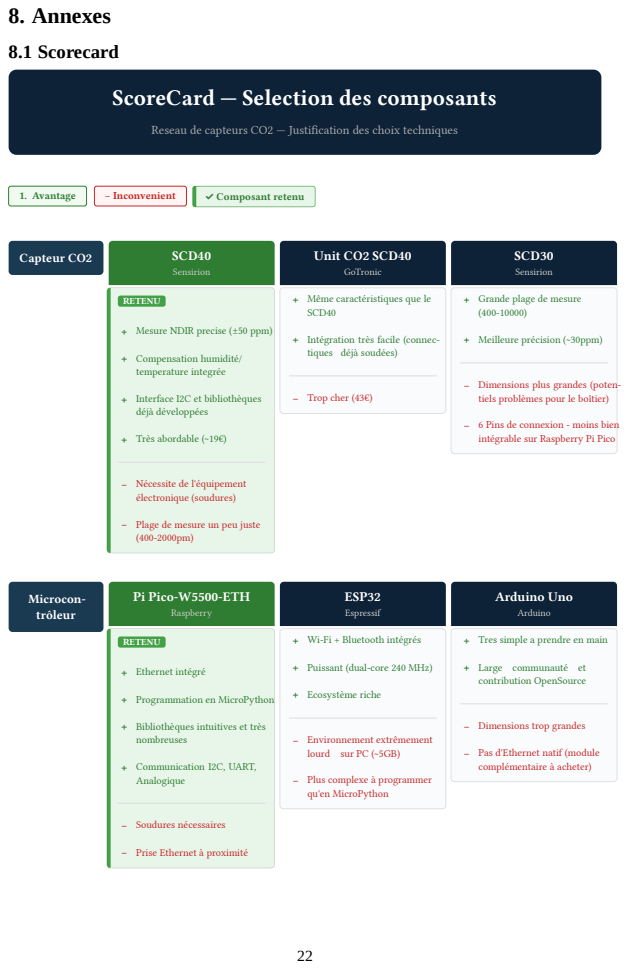
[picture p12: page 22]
8.1 Scorecard; 1. Avantage; − Inconvenient; ✓ Composant retenu; Capteur CO2; SCD40; Sensirion; RETENU; + Compensation humidité/ temperature integrée; + Très abordable (~19€); Unit CO2 SCD40; GoTronic; − Trop cher (43€); SCD30; + Meilleure précision (~30ppm); Microcon' trôleur; Raspberry; + Ethernet intégré; + Communication I2C, UART, Analogique; − Soudures nécessaires; ESP32; Espressif; + Ecosystème riche; Arduino Uno; Arduino

Reseau de capteurs CO2 — Justification des choix techniques

+ Même caractéristiques que le
SCD40

+ Grande plage de mesure

+ Mesure NDIR precise (±50 ppm)

+ Intégration très facile (connec-
tiques déjà soudées)

− Dimensions plus grandes (poten-
tiels problèmes pour le boîtier)

+ Interface I2C et bibliothèques
déjà développées

− 6 Pins de connexion - moins bien
intégrable sur Raspberry Pi Pico

− Nécessite de l'équipement
électronique (soudures)

− Plage de mesure un peu juste

Pi Pico'W5500'ETH

+ Wi-Fi + Bluetooth intégrés

+ Tres simple a prendre en main

+ Puissant (dual-core 240 MHz)

+ Large communauté et
contribution OpenSource

+ Programmation en MicroPython

+ Bibliothèques intuitives et très
nombreuses

− Dimensions trop grandes

− Environnement extrêmement
lourd sur PC (~5GB)

− Pas d'Ethernet natif (module
complémentaire à acheter)

− Plus complexe à programmer
qu'en MicroPython

− Prise Ethernet à proximité

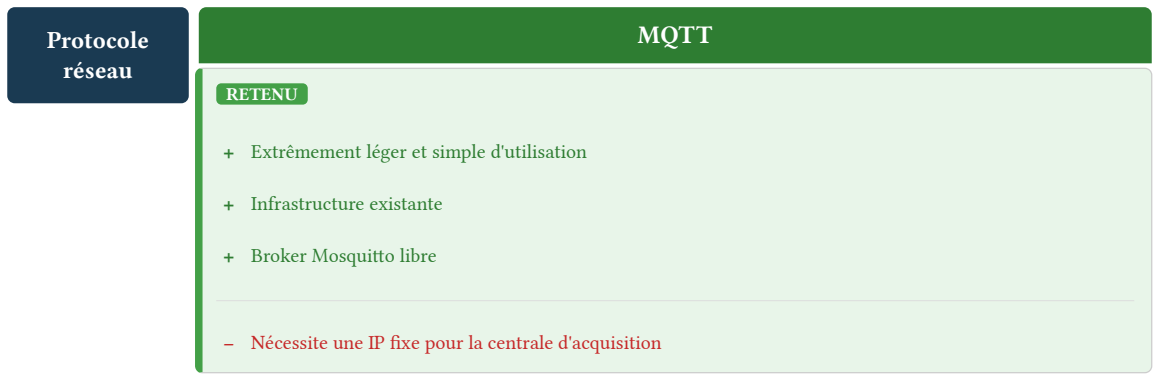
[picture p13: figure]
Protocole réseau; MQTT; RETENU; + Infrastructure existante; + Broker Mosquitto libre

+ Extrêmement léger et simple d'utilisation

− Nécessite une IP fixe pour la centrale d'acquisition

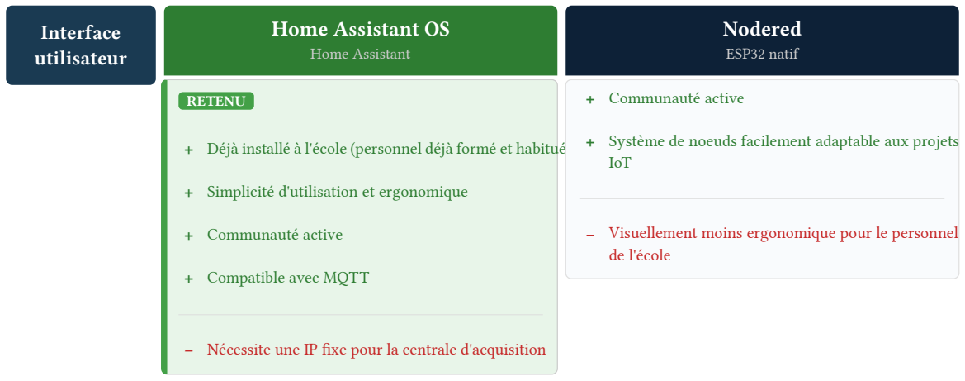
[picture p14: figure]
Interface utilisateur; Home Assistant OS; Home Assistant; RETENU; + Simplicité d'utilisation et ergonomique; + Communauté active; + Compatible avec MQTT; Nodered; ESP32 natif; IoT; de l'école

+ Déjà installé à l'école (personnel déjà formé et habitué)

− Nécessite une IP fixe pour la centrale d'acquisition

+ Système de noeuds facilement adaptable aux projets

− Visuellement moins ergonomique pour le personnel

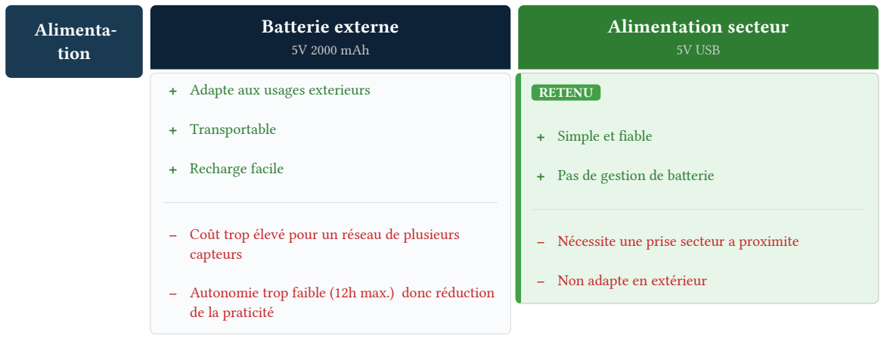
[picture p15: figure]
Alimenta' tion; Batterie externe; 5V 2000 mAh; + Adapte aux usages exterieurs; + Transportable; + Recharge facile; capteurs; de la praticité; Alimentation secteur; 5V USB; RETENU; + Simple et fiable; + Pas de gestion de batterie; − Non adapte en extérieur

− Coût trop élevé pour un réseau de plusieurs

− Autonomie trop faible (12h max.) donc réduction

− Nécessite une prise secteur a proximite

# Comparaison avec un équivalent commercial

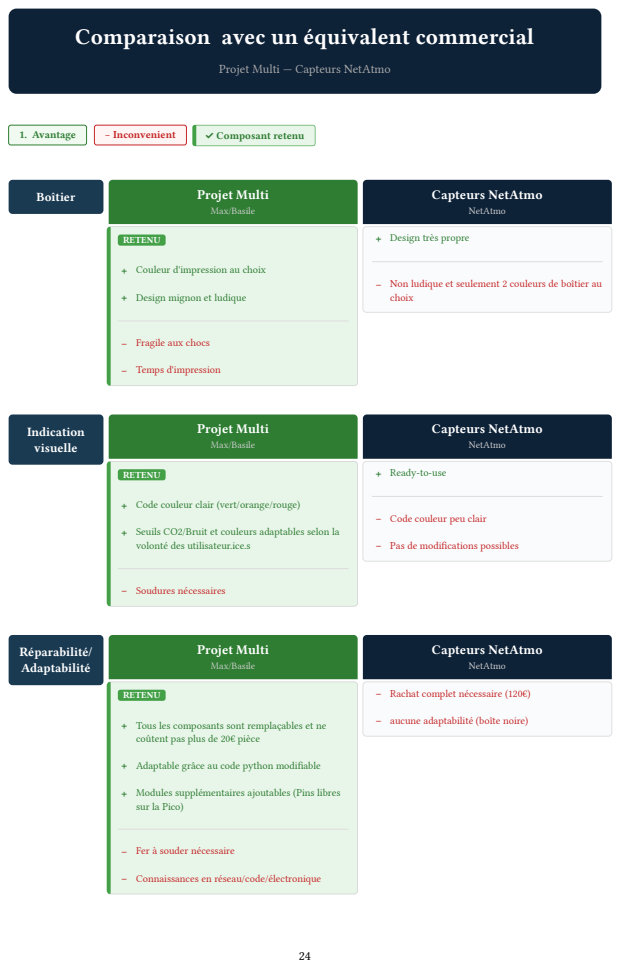
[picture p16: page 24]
1. Avantage; − Inconvenient; ✓ Composant retenu; Boîtier; Projet Multi; Max/Basile; RETENU; − Temps d'impression; Capteurs NetAtmo; NetAtmo; Indication visuelle; − Soudures nécessaires; Réparabilité/ Adaptabilité

Projet Multi — Capteurs NetAtmo

+ Design très propre

+ Couleur d'impression au choix

− Non ludique et seulement 2 couleurs de boîtier au
choix

+ Design mignon et ludique

− Fragile aux chocs

+ Ready-to-use

+ Code couleur clair (vert/orange/rouge)

− Code couleur peu clair

+ Seuils CO2/Bruit et couleurs adaptables selon la
volonté des utilisateur.ice.s

− Pas de modifications possibles

− Rachat complet nécessaire (120€)

− aucune adaptabilité (boîte noire)

+ Tous les composants sont remplaçables et ne
coûtent pas plus de 20€ pièce

+ Adaptable grâce au code python modifiable

+ Modules supplémentaires ajoutables (Pins libres
sur la Pico)

− Fer à souder nécessaire

− Connaissances en réseau/code/électronique

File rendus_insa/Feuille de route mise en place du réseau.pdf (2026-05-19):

## Feuille de route - Installation réseau de capteur

07/05/2026

## ETAPE 1 (8h-9h) : Arrivée

- Arrivée depuis Paris
- Visite des différentes salles, familiarisation avec l’école

## ETAPE 2 (9h-9h20) : Matériel

- Prise en main matériel (câbles ethernets, pi 4, présentation du boitier capteur, …)
- Installation et branchement (Pi 4, boitier capteur, PC central)

## ETAPE 3 (9h20-10h) : Initialisation HA

- Connexion à HA depuis le PC central
- Mettre à jour le HA en suivant le guide d’utilisation (config mqtt et copie du yaml)

## ETAPE 3bis (9h20h-10h) : Réseau

- Récupération des adresses IP du réseau : Routeur, DNS, Passerelle, Pi Pico, Pi 4
- Implémentation dans le main.py et sur HA (mqtt)

## ETAPE 4 (10h-10h30) : Test

- Test de communication avec un boitier branché sur un PC portable
- Test avec les boitiers branchés sur secteur
- Test dans les salles définitives

## ETAPE 5 (10h30 – 12h00) : Débogage

- Résolution des potentiels problèmes (capteur CO2, réseau, indice ICONE, LED, heure d’automation, …)

## ETAPE 6 (11h30-12h) : Calibration

- Calibration des SCD40 grâce à un capteur industriel depuis HA.

## ETAPE 7 (14h-…) : Amélioration

- Discussion et mise en place d’amélioration dans le code et sur l’interface.
- Ajout d’automations pour les vacances
- Contrôle des seuils d’alerte (800/1500ppm) depuis HA

## ETAPE 8 (dernière demi-heure) : Mise en place finale

- Mise en place des capteurs dans les salles définitives et test final.

Matériel amené par les étudiants | Matériel nécessaire
2 loutres creuses | 1 Scotch
2 ventres transparents | 4 câbles Ethernets
1 casquette | 1 Pi 4 de l’école
2 Pi Pico + 2 Shield | 1 PC central de la gestionnaire
1 Paquet fils connectique Shield
2 SCD40 avec leur connectique
2 capteurs de bruit avec leur connectique
2 bandeaux LEDs avec leur connectique 1 Bandeau LEDs complet
1 paquet de broches Pi Pico-Shield
2 boîtiers d’alimentations Pi Pico
1 câble HDMI
2 PC portables

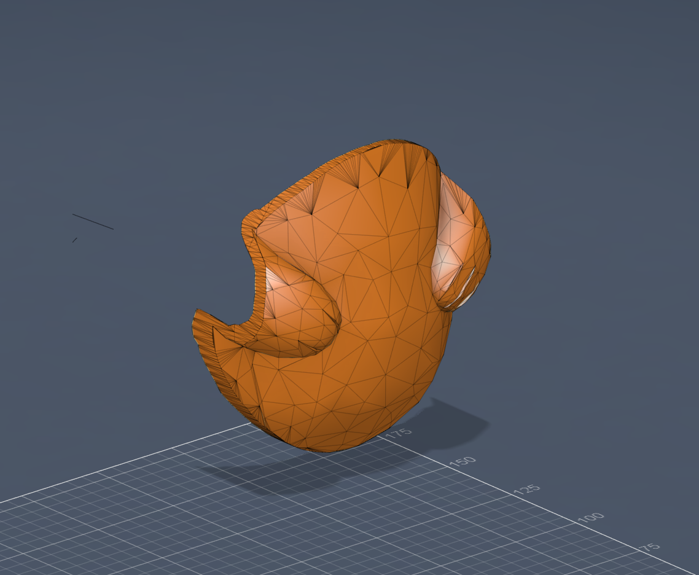
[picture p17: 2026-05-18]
impression_3d/Fichiers pour impression/Ventre VF.png

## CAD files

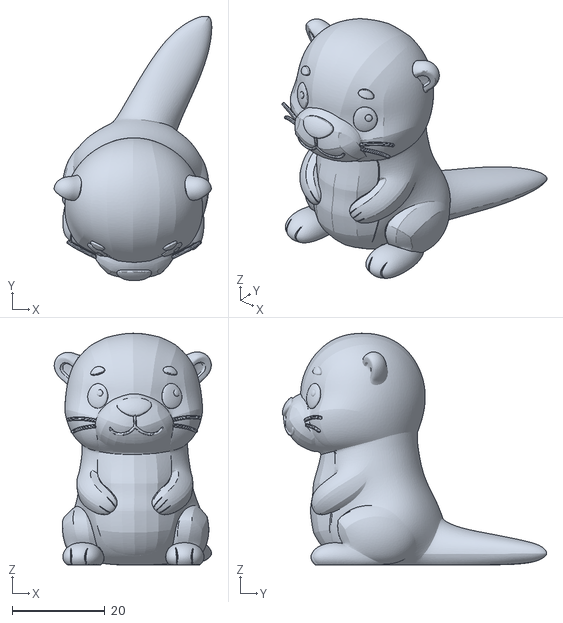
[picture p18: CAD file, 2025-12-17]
impression_3d/Fichier d'origine/Mini_Otter.stl
34.0 x 57.0 x 50.0

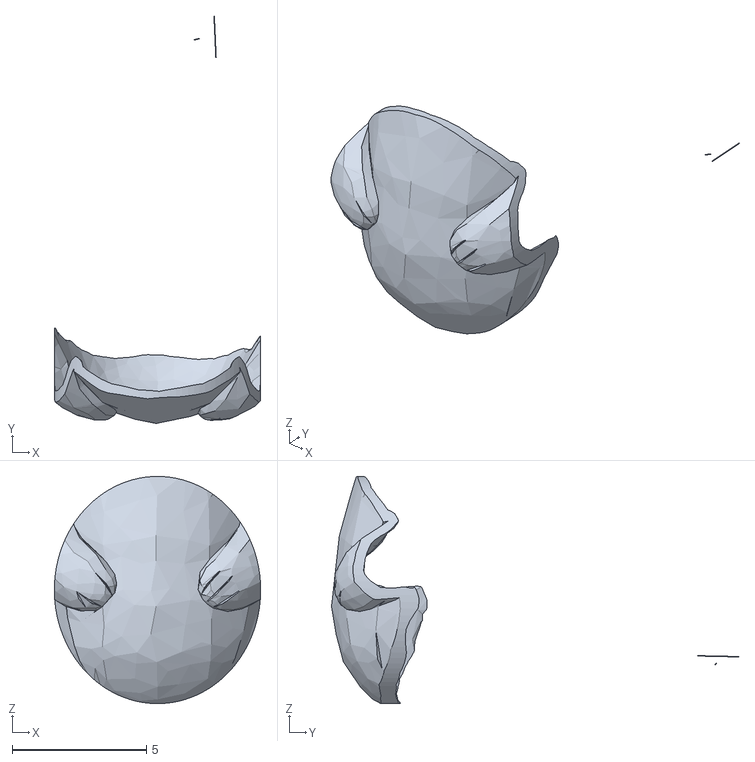
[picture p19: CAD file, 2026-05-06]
impression_3d/Fichiers pour impression/LOUTRE_VENTRE_VF.stl
7.67 x 15.1 x 8.44

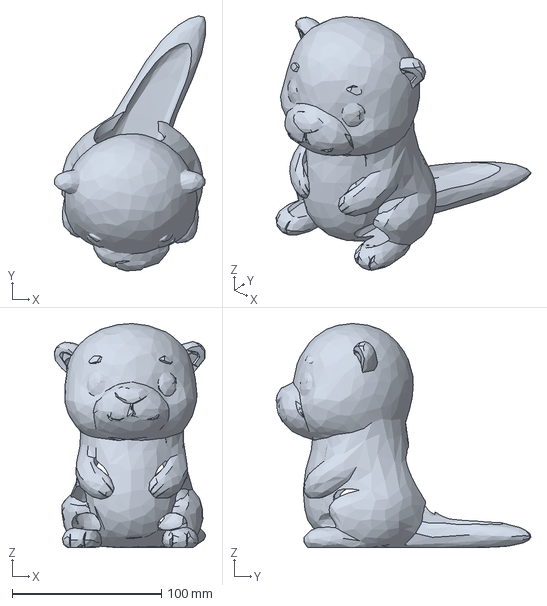
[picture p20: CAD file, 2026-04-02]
impression_3d/premier essai fablab 27012026/UCP_moustache1.3mf
101.3 x 170.7 x 150.0 mm

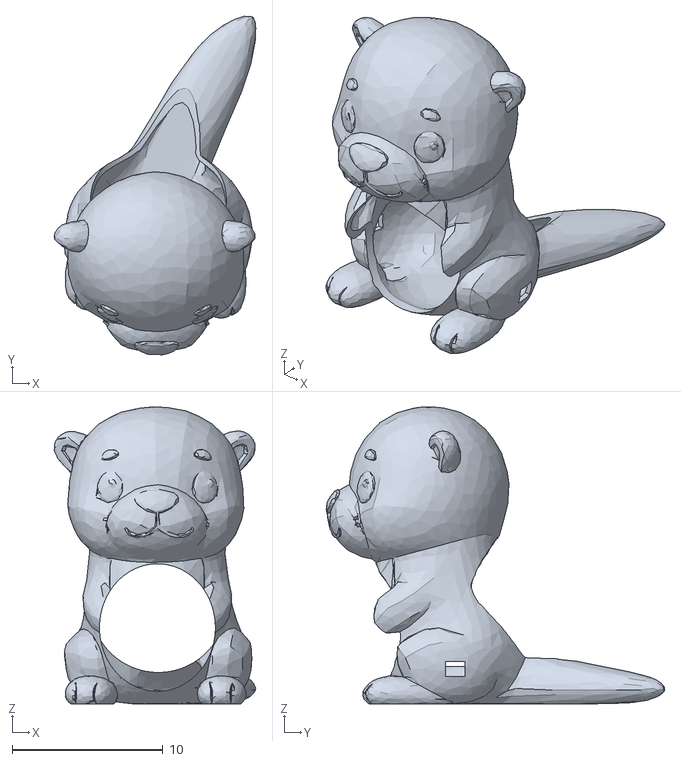
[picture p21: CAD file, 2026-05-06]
impression_3d/Fichiers pour impression/LOUTRE_CREUSEE_VF.stl
13.4 x 22.4 x 19.7

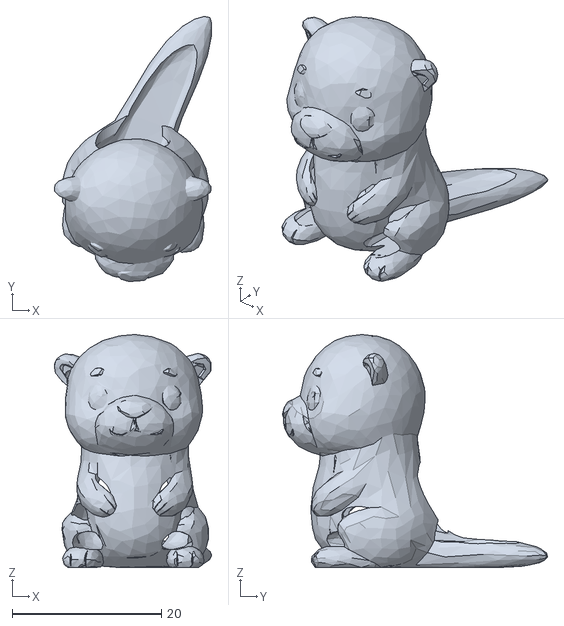
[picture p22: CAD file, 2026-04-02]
impression_3d/premier essai fablab 27012026/moustache1.stl
21.1 x 35.5 x 31.2

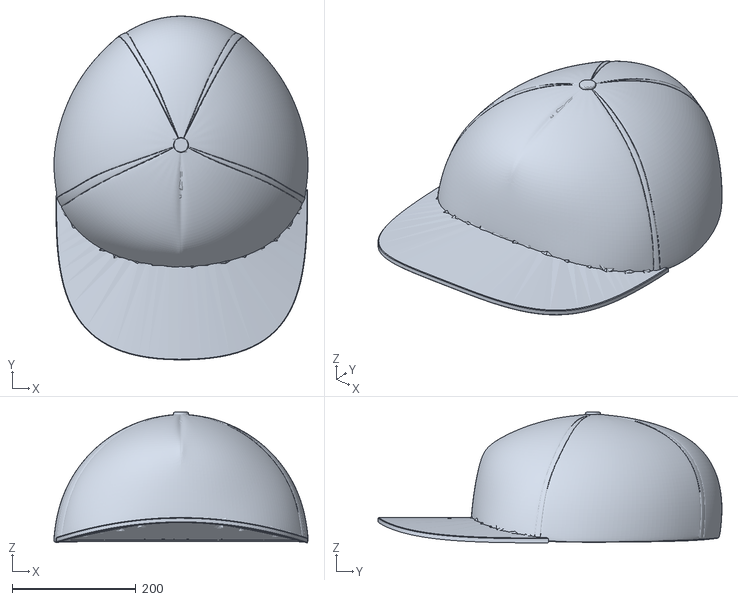
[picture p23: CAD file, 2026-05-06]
impression_3d/Fichiers pour impression/CASQUETTE_CREUSE.stl
410.1 x 555.1 x 211.2

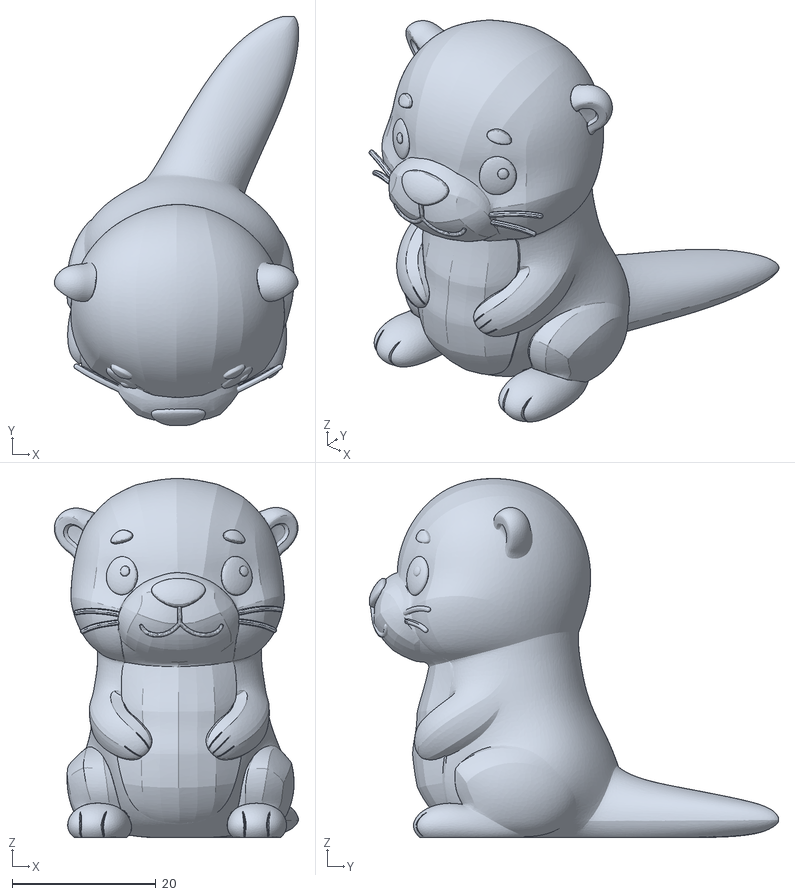
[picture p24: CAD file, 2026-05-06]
impression_3d/Fichiers pour impression/LOUTRE_TROUEE_0.7mm.stl
34.0 x 57.0 x 50.0

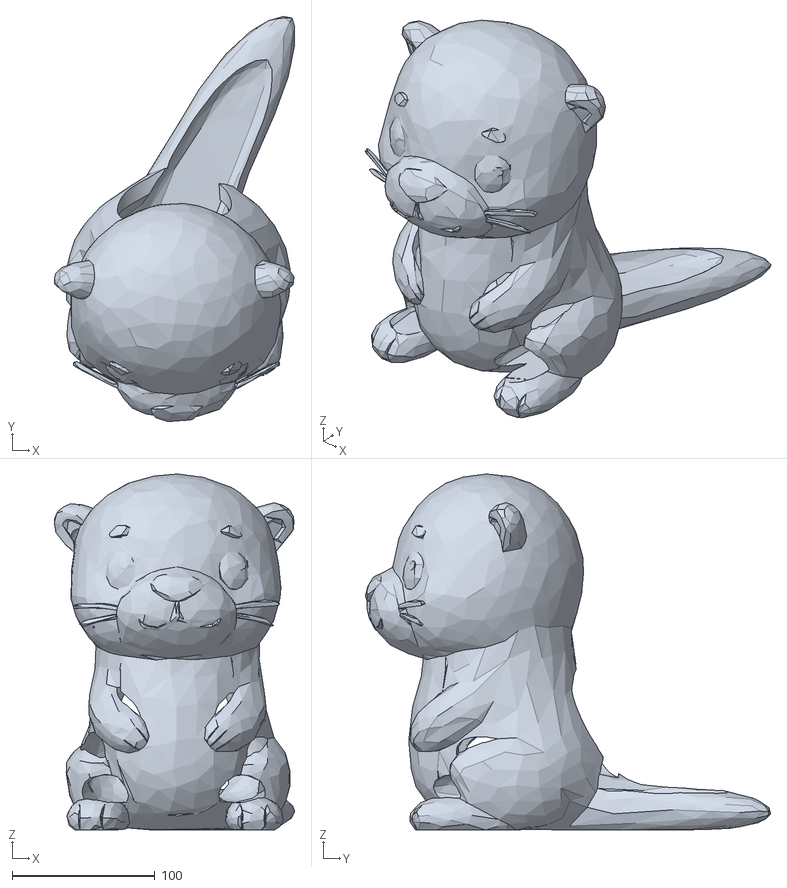
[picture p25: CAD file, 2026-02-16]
impression_3d/premier essai fablab 27012026/basile.stl
168.7 x 284.3 x 249.8

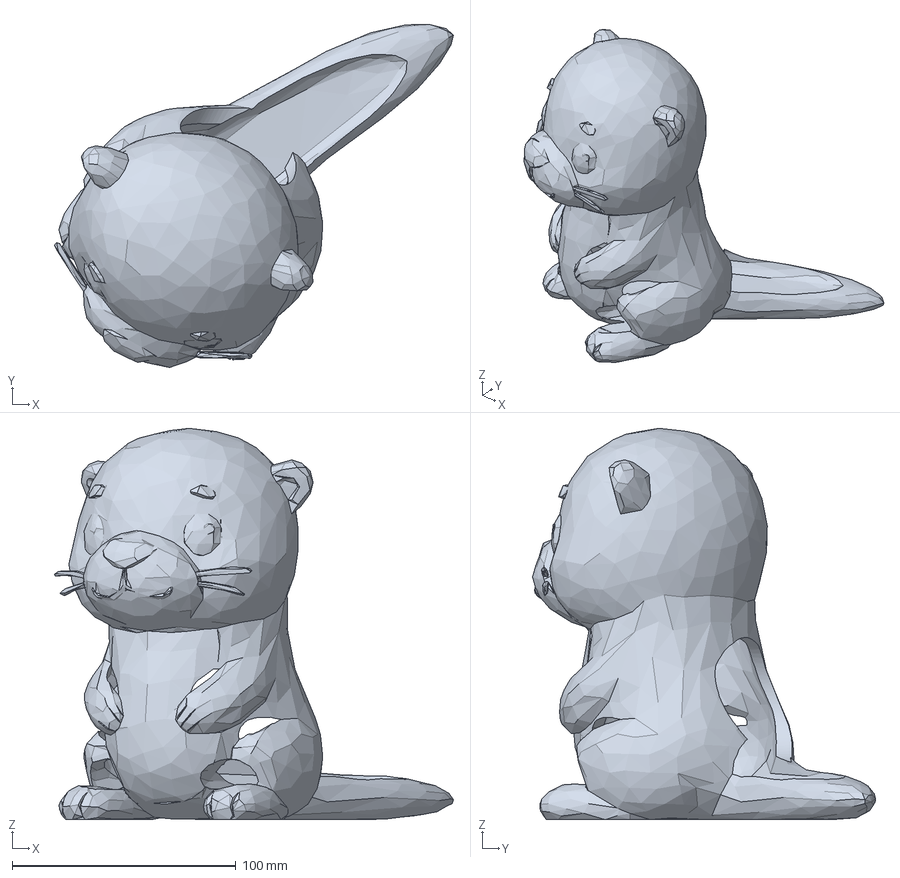
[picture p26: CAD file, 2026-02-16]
impression_3d/premier essai fablab 27012026/UMS5_basile.3mf
178.3 x 153.3 x 174.8 mm

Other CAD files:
impression_3d/premier essai fablab 27012026/moustache1.blend

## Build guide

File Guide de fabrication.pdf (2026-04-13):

# Guide de fabrication

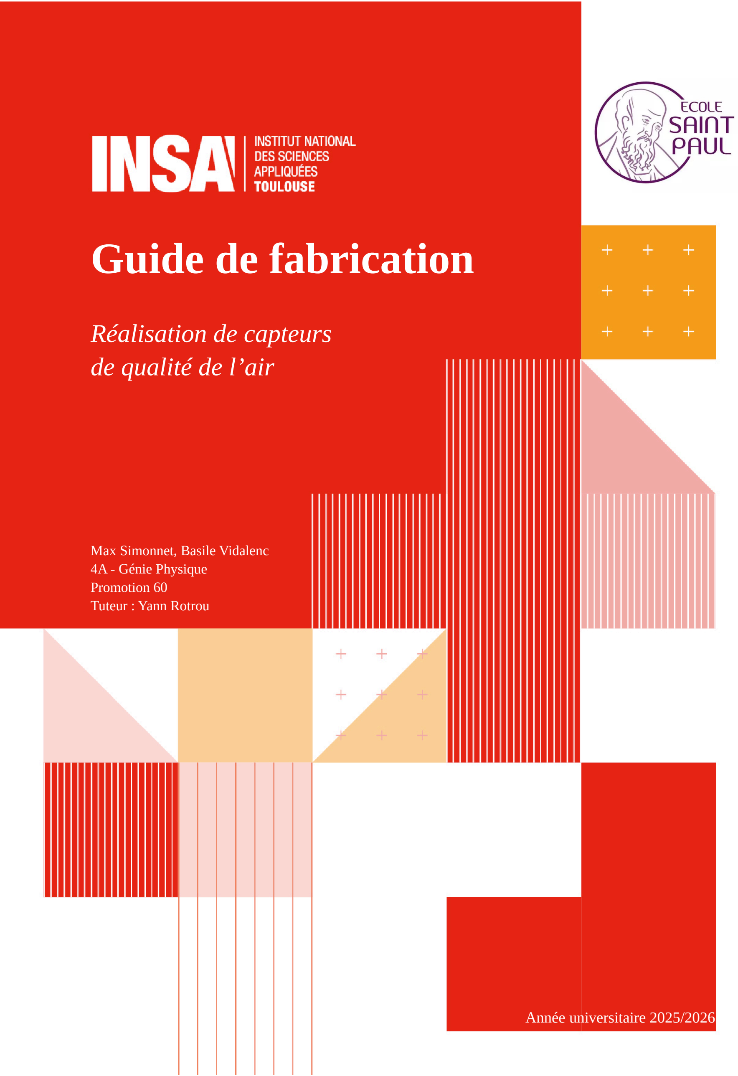
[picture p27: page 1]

## Réalisation de capteurs de qualité de l’air

Max Simonnet, Basile Vidalenc 4A - Génie Physique
Promotion 60
Tuteur : Yann Rotrou

Année universitaire 2025/2026

## 1. Table des matières

A faire :
- rajouter une condition vacance sur HA
- Rapports hebdomadaires/mensuels
- finir la salle 1 et l’étendre à la salle 2 (et pour toutes les salles ?)
- Manuel de fabrication
- Finir la procédure test ethernet notament la partie MQTT et github
- Loutre

## 2. Présentation de l’outils

### 2.1 Contexte

Au niveau international, l’Organisation mondiale de la Santé (OMS) fournit des recommandations visant à protéger la santé des enfants et des adolescents. L’OMS établit des valeurs guides pour les concentrations de polluants atmosphériques dans les espaces intérieurs, notamment :

- Particules fines (PM2,5) : concentration annuelle moyenne inférieure à 5 µg/m³.
- Particules fines (PM10) : concentration annuelle moyenne inférieure à 15 µg/m³.
- Dioxyde de carbone (CO₂) : concentration inférieure à 800 ppm pour garantir une ventilation adéquate et maintenir la concentration et la vigilance.
- Température intérieure : plage recommandée entre 18 et 22 °C pour assurer le confort thermique.
- Humidité relative : plage recommandée entre 30 % et 60 % pour prévenir les risques de moisissures et garantir le confort.
- Niveau sonore : niveau sonore inférieur à 35 dB(A) pour favoriser la concentration et l’apprentissage.

### 2.2 Rendu final

### 2.2.1 Le boîtier d’acquisition

### 2.2.2 L’interface utilisateur

## 3. Matériel

### 3.1 Github

Notre projet et tout son contenu est entièrement disponible sur notre Github à cette adresse : https://github.com/Makssse/Projet-Multidisciplinaire/tree/main

Vous y trouverez notament les codes Home Assistant et Python, le design pour la coque du capteur, et tout les fichiers nécessaire à la mise en place informatique et réseau.

### 3.2 Ressources et aides

Notre Ghitub, mettre les liens vers le site raspberry, micropython

Vidéo ytb introduction au code micropythpn : https://www.youtube.com/watch?v=Ic4 ExTusoTw (https://www.youtube.com/watch?v=Ic4ExTusoTw)

site pour mettre en marche vs code et la pi pico : https://tutoduino.fr/pico-python-visual-studiocode/ (https://tutoduino.fr/pico-python-visual-studio-code/)

Site pour utilise le capteur grove : https://wiki.seeedstudio.com/Grove-Loudness_Sensor/

Datasheet raspberry pour internet et pi pico : https://datasheets.raspberrypi.com/picow/connecting-to-the-internet-with-pico-w.pdf (https://datasheets.raspberrypi.com/picow/connecting-to-the-internet-with-pico-w.pdf)

### 3.3 Infrastructure et réseau

Parler des ordis, réseau ethernet

### 3.4 Outils

Fablab

### 3.5 Matériel à acheter

Le matériel décrit ci dessous est celui que nous avons utilisé. Il est possible bien sûr en explorant les fiche technique de changer tout ou partie du matériel utilisé si vous le voulez. Aussi pour faire nos achat nous avons utilisé les sites Moser et Gotronik qui proposait des prix très intéressants. Vous pouvez utiliser toute plateforme marchande ou se trouve le matériel.

Composante | Prix (€) | Description | Datasheet
Raspberri 4B | 65 | Ordinateur monocarte sous Linux agissant comme centrale d’acquisition via ses GPIO et serveur de base de données
Raspberry Pi Pi-co W5500-EVB (RP2040) | 14 | Carte de développement basée sur le microcon-trôleur RP2040 couplée à un contrôleur Ethernet W5500.
Capteur SCD 40 sur PCB | 20 | Module de mesure miniaturisé basé sur la technolo-gie NDIR, mesurant le taux de CO2, la température et l’humidité relative. Il communique via le bus I2C.
Grove-Loundness Sensor | 7 | Module de détection sonore analogique mesurant l’intensité du bruit ambiant.
LED adressables | 10 | Éclairage RVB numérique permettant le pilotage individuel de la colorimétrie de chaque pixel via une unique ligne de données.
Carte SD 8GB | 5 | Support de stockage flash hébergeant le système d’exploitation du Raspberry Pi, l’environnement logiciel et des données locale.
Grove shield pour Pi Pico | 6 | Carte d’interface matérielle adaptant les GPIO du Raspberry Pi Pico vers le standard de connectique Grove
Raspberry Pi Pico Po-wer Supply | 5 | Source d’énergie externe délivrant une tension ré-gulée de 5V via Micro-USB

Cable HDMI

Cable Grove
Cable Micro USB

## 4. Montage

### 4.1 Soudures

La Raspberry Pi Pico est fournie avec des broches qu’il faut souder aux « pins » (trous numérotés sur les côtés). Les soudures sont standards et vous pouvez faire cela dans un fablab, qui dispose de tous les équipements nécessaires.

### 4.2 Le Grove shield

### 4.2.1 Branchement des capteurs et modification du code

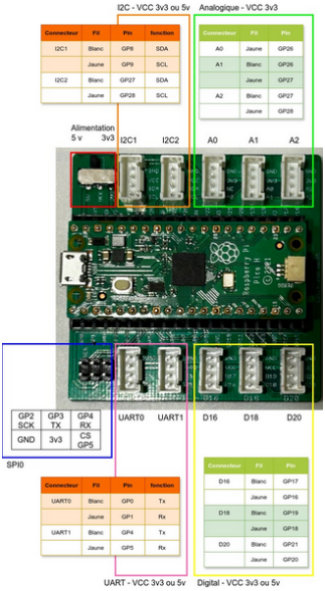
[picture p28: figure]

Fig. 1. – Image montrant les correspondances entre le Shield et les pins de la Pi Pico (https://www.sugarbug.fr/index.php/tutos-lego/le-grove-shield-pour-le-pi-pico)².

### 4.2.2 Soudure des Leds

### 4.3 Fabrication du PCB pour le SCD 40

### 4.4 Fabrication de la coque

### 4.4.1 Modélisation avec Fusion 360

Nous avons pu utiliser le logiciel Fusion 360 grâce à une licence de notre école. Mais il existe d’autres logiciel libre de droit comme : NANANANA.
Nous avons récupérer un modèle qui existait déjà sur ce site : NANANA et nous l’avons modifier pour nos besoin. Vous retrouverez le fichier .stl prêt pour impression sur le Ghithub sous le nom : NANANA.
Il est possible également de récuper des design déjà fait sur des sites comme : NANAAN. Puis de modifier, en prenant en compte le matériel et les capteurs à mettre dans la coque, ainsi que quelques trous pour que l’air à l’intérieur du boîtier d’acquisition soit similaire à l’air de la pièce. Il est sinon possible de créer à partir de zéro sa coque mais cela demande plus de temps.

### 4.4.2 Impression 3D

### 4.5 Montage final du capteur

## 5. Mise en place de l’informatique et codage

### 5.1 Préparation des Raspberrys

### 5.1.1 Installation de Home Assistant sur la Raspberry Pi 4B

Pour l’installation, il est nécessaire d’avoir une carte micro-SD (normalement fournie lorsqu’on achète une Raspberry Pi 4B avec son câble d’alimentation). Sur le site de Raspberry, téléchargez le Raspberry Pi Imager puis ouvrez l’application.

- Sélectionnez votre « device » (ici la Raspberry Pi 4) puis choisissez l’OS (Operating System) : « Other specific purpose OS » -> « Home automation » -> « Home Assistant OS (RPi4/400) »
- Sélectionnez ensuite la carte SD dans l’onglet « Select your storage device »
- Cliquez sur « Suivant » 2 fois sans vous préoccuper de l’onglet « Customisation »
- Lorsque l’opération de flashage de la carte SD est finie, débranchez-la de votre ordinateur et branchez-la sur la RPi 4B.
- Branchez le câble d’alimentation : Home Assistant s’installe sur la RPi 4B.

### 5.1.2 Installation de MicroPython sur la Raspberry Pi Pico

Afin de pouvoir exécuter des programmes en Python sur notre Pico, nous avons besoin de MicroPython, l’implémentation du langage Python 3 conçu pour les microcontrôleurs.

Pour commencer nous allons avoir besoin d’installer l’interpréteur MicroPython sur le Pico afin de pouvoir y exécuter nos programmes écrits en Python.

Le Pico doit être en mode Bootloader. Pour cela appuyez sur le bouton BOOTSEL et maintenezle enfoncé tout en connectant votre Pico à un ordinateur à l’aide d’un câble USB. Relâchez le bouton BOOTSEL une fois que votre Pico apparaît comme un périphérique de stockage de masse appelé RPI-RP2.

Télécharger la dernière version du binaire (format UF2) de MicroPython pour Raspberry Pi Pico sur le site https://micropython.org/download/RPI_PICO/ et glisser-déposer le fichier UF2 sur le périphérique de stockage de masse RPI-RP2. Attention de bien prendre celui avec l’extention ethernet. Sinon vous pouvez le trouver sur notre github.

Votre Pico va redémarrer et ne sera plus vu comme un périphérique de stockage de masse, il exécute maintenant MicroPython et est prêt à recevoir votre code Python pour l’exécuter.

### 5.2 Environnement VS code

Nous avons utilisé VScode pour coder. L’installer et savoir s’en servir n’est pas nécessaire pour fabriquer et utiliser les capteurs cependant il peut être utile pour les personnaliser et savoir se plonger dans le code. Attention cependant toute la partie relative au code demande un certain niveau notamment en langage python. Il est également possible d’utiliser d’autres environnement comme Thonny.

### 5.2.1 VScode pour la Pi Pico

Télécharger Visual Studio Code.

Lancer Visual Studio Code et installer l’extension MicroPico , Raspberry Pi Pico et Python.

Créer un répertoire Python Pico et y créer un fichier main.py. Nommer votre fichier main.py lui permet de s’exécuter directement au démarrage du Raspberry Pi Pico.

Dans Visual Studio Code, cliquer sur l’icône Explorer et Open Folder afin d’ouvrir le répertoire Python Pico.Une fois le répertoire ouvert sélectionner le fichier main.py et appuyer sur les touches CTRL+SHIFT+P, puis cliquer sur « MicroPico: Configure MicroPico Project ».

Une fois que votre programme est finalisé, vous pouvez le téléverser sur le Pico en cliquant avec le bouton droit de la souris dans le répertoire puis sur « Upload project to Pico. » Votre programme est maintenant prêt à être exécuté, il suffit de cliquer sur l’icône Run en bas de la fenêtre.

Attention si il y a déjà des fichiers sur la pico il est conseillé d’appuyer sur les touches CTRL+SHIFT+P, puis cliquer sur « MicroPico: Delete all file on Micropico ». Puis de déconnecté/reconnecté matériellement votre pico, puis de upload à nouveau votre projet.

### 5.2.2 Librairies python

### 5.2.3 Mise à jour du « main » de la Pico

### 5.3 Importation du code sur les Raspberrys

### 5.4 Mise en place de l’interface HA

Nous allons dans cette section décrire la mise en place de l’environnement HA. Il est conseillé de s’aider également de tutos. Et de prendre HA, qui est un outils très intuitif en main pour ensuite faire vos propres interfaces et améliorations.

Home Assistant (HA) est un système d’exploitation spécialisé dans la domotique installable sur la Raspberry Pi 4.

### 5.4.1 Création d’un utilisateur

Connecter au meme réseau ethernet votre Pi 4 et votre ordinateur puis sur le navigateur web de votre ordinateur, taper https://homeassistant:8123
Mettez votre mdp et nom tout en minuscule. Il faut ensuite changer votre mdp et nom dans le fichier python main.py aux endroit mentionné dans le fichier.

### 5.4.2 Installation Mosquito Broker et configuration

Sur votre interface Home Assistant :
- Cliquer sur « Paramètres » → « Modules complémentaires » → « Boutique des modules complémentaires »
- Dans la barre de recherche, tapez « MQTT Broker »
- Cliquez sur le résultat « MQTT Broker » puis installez-le

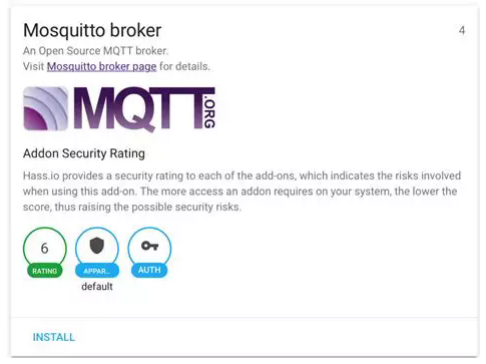
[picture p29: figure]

Fig. 2. – MQTT Broker, résultat dans la barre de recherche Home Assistant

)
Une fois Mosquitto installé :
- Étape 1 : Paramètres/Appareils et services/MQTT/Reconfigurer (disponible via les 3 petits points).
- Etape 2 :
- Courtier : IP de votre Raspberry pi 4
- Port : 1883
- nom d’utilisateur et mdp de votre utilisateur

### 5.4.3 Modification du fichier « configuration.yaml »

Pour repérer nos différentes grandeurs mesurées ont va déclaré dans le fichier configuration.yaml de HA nos différents capteurs. Vous avez sur notre ghithub le fichier « configuration yaml pour capteur » qui donne un exemple pour configurer les 4 capteurs (température, CO2, bruit, humidité) de la salle 1. Il faut reproduire ce code pour les autres salle.

- Étape 1 : Sur HA- Paramètre/Apps/Installer Studio Code Server

- Etape 2 : Lancer Studio Code Server et copier à la fin du fichier « configuration.yaml » les déclarations de capteurs disponible sur notre github.
- Etape 3 : Sauvegarder puis Paramètres/Outils de dévellopement/YAML/Rechargement de la configuration YAML et cliquer sur « Toute la configuration YAML » et « Entités MQTT ».

Vous pouvez maintenant aller dans Paramètres/Appareils et services/Entités et vous pouvez apercevoir vos différents capteurs de vos différentes salles.

### 5.4.4 Modification du fichier « script.yaml »

Copier le fichier script.yaml disponible sur le Github. Il permet de relier le bonton d’envoie au valeur de l’offset de température et au taux de CO2 voulu pour calibrer le SCD40.

### 5.4.5 Création de votre tableau de bord

Carte et indicateurs
Nous avons maintenant un espace utilisateurs et nos différentes entités/capteurs sur HA. Nous allons créer un tableau de bord pour visualiser nos données en temps réel.
- Etape 1 : Sur HA- Paramètres/Tableaux de bord/Ajouter un tableau de bord/Nouveau tableau de bord vide.
- Etape 2 : Dans votre tableau de bord qui apparaît dans le volet de gauche. Cliquer sur le stylo en haut à droite, cliquer sur Editeur de configuration, coller notre code « tableau de bord » sur le github.

Vous pouvez sinon créer le votre en ajoutant des cartes. Un exemple simple est de selectionner la carte « jauge » et d’y associer l’entité CO2 salle 1.

Interrupteur générale
Il vous faut ensuite si vous voulez utiliser la fonction de l’interrupteur générale (utile si vous avez plus d’un capteur) aller dans : « Paramètres/Appareils et services/Entrées/Créer une entrée/ Groupe/Groupe d’interrupteurs » puis vous sélectionnez vos interrupteurs de salles. Ensuite dans votre tableau de bord vous pouvez créer une carte entités avec cet interrupteur générale qui vous permet de gérer tout les interrupteurs.

### 5.4.6 Création d’automation

## 6. Mise en place réseau

### 6.1 Test de la connexion ethernet

Nous allons dans cette partie détailler la procédure pour tester la connexion et la communication ethernet nécessaire dans le cadre du projet. Voici la liste du materiel nécessaire :
- Une raspberry Pi pico
- Une raspberry Pi 4
- Un ordinateur avec connexion ethernet
- Un ordinateur portable
- 3 cables ethernet

Le but est uniquement de s’assurer que notre réseau ethernet est fonctionnel et que la pi pico peut envoyer des données sur Home Assistant grâce à la communication MQTT.

- Installer HA sur la Pi 4 ainsi que l’extention Mosquitto Broker et configurer la communication MQTT (Chapitre 5.1.1)
- Initialiser l’environnement code de la pi pico avec VS Code (Chapitre 5.2)
- Télécharger les fichiers disponibles sur le Github (Chapitre 3.1) dans le fichier test_ethernet. Modifier maintesteth.py en suivant les instruction dans le code, notamment l’IP de la Rasp Pi 4, l’IP de la pi pico et les infos utillisateur.
- Charger sur la pi pico les fichiers disponibles sur le Github (Chapitre 3.1) dans le fichier test_ethernet et le fichier maintesteth.py maintenant modifié. Runner, tout en étant connecté sur le PC portable pour avoir des infos sur la console, le programme maintesteth.py.
- Sur HA aller dans Paramètres/Appareils et services/MQTT/Configurer/Ecouter un sujet
- Dans sujet auquel s’abonner mettre : # et dans QoS : 1 puis cliquer sur Commencer à écouter.
- Des données devrait apparaître sur HA.

### 6.2 Branchement

### 6.3 Initialisation

## 7. Utilisation

## 8. Débogage et maintenance

## 9. Annexe

### 9.1 Les différentes communiations

### 9.1.1 Communication en I2C

### 9.1.2 Communication SK (led)

### 9.1.3 Communication ethernet : protocole MQTT

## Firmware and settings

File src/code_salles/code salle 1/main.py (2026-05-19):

#code pour la pi pico de la salle 1
import time
from machine import WDT, Pin 

time.sleep(1)
led = Pin("LED", Pin.OUT)
for _ in range(10): # Clignote très vite 10 fois
    led.value(1); time.sleep(0.05)
    led.value(0); time.sleep(0.05)

import uasyncio as asyncio
import ujson
import sys


from lib_scd4x import *
from lib_led import *
from lib_mqtt import *
from lib_son import config_port_son, niveau_sonore
from lib_IP_MAC import connect_ethernet

SALLE_ID = "salle1" # A CHANGER SELON PICO c'est la seule ligne à changer avc IP_BROKR

# on récupère l'IP et l'adresse MAC de la pico 
mac_pico, ip_pico = connect_ethernet()
print(f"mac = {mac_pico}")
print(f"ip = {ip_pico}")

# ------------------ ÉTAT DU SYSTÈME ------------------ #
systeme_actif = True  # Le système démarre "Allumé" par défaut

# ------------------ CONFIGURATION MQTT ------------------ #
IP_PICO = ip_pico  
MAC_PICO = mac_pico 
BROKER_IP = "192.168.2.10" #a changer selon le réseau
MQTT_USER = "ecolesaintpaulqai"      # Minuscule comme dans ton test
MQTT_PASS = "MmeM011ier!"  # Ton mot de passe qui fonctionne
INTERVALLE_MQTT = 10         # Envoi toutes les 10 secondes sur HA pour commencer
SEUIL_CO2_OK = 1200.0         #seuil pour les ppm du CO2
SEUIL_CO2_ALERTE = 2000.0
SEUIL_BRUIT_ALERTE = 2000   # Ajuster selon la sensibilité (potentiomètre) du capteur Grove
#CIBLE_CALIBRATION_CO2 = 400.0

# ------------------ CONFIGURATION MATERIELLE PI PICO ------------------ #
# pour le capteur scd sur I2C0 de la shield
PIN_SDA = 8
PIN_SCL = 9
PORT_SCD = 0
# altitude du capteur (à spécifier)
ALTITUDE = 0

#pour les leds, config qui fontionne pour branchement des LEDs sur UART0 ou 0,1,Vcc,GND
NUM_LEDS = 6        # Nombre de LEDs sur ta bande
PIN_DATA = 1        #green (data)
PIN_CLOCK = 0       #blue (clock)
BRIGHTNESS = 0.5    # Luminosité (0.1 à 1.0)

# pour le capteur de son
PIN_SON = 26



# Dictionnaire des variables globales pour partager les données entre les tâches
donnees_actuelles = {"co2": 0, "temp": 0, "humi": 0, "bruit": 0}

# ------------------ FONCTIONS MQTT ------------------ #

def reception_message(topic, msg):
    """ Cette fonction s'exécute dès qu'un message MQTT arrive """
    global systeme_actif
    global SEUIL_CO2_ALERTE
    global SEUIL_CO2_OK
    # On s'assure que 'msg' est bien une chaîne de caractères propre
    if isinstance(msg, bytes):
        ordre = msg.decode().strip()
    else:
        ordre = str(msg).strip()
        
    print(f" Ordre reçu : [{ordre}] sur le topic [{topic}]")

    if ordre == "OFF":
        systeme_actif = False
        print(" Système mis en PAUSE")
    elif ordre == "ON":
        systeme_actif = True
        print(" Système RÉVEILLÉ")

    elif ordre.startswith("OFFSET:"):
        try:
            systeme_actif = False
            valeur = float(ordre.split(":")[1])
            print(f"Application du nouvel Offset : {valeur}°C")
            change_parametres(scd, valeur, ALTITUDE)
            systeme_actif = True
        except Exception as e:
            print("Erreur lors de l'application de l'offset:", e)
            
    elif ordre.startswith("CALIBRER:"):
        try:
            systeme_actif = False
            valeur = int(float(ordre.split(":")[1]))
            print(f"Calibration forcé à : {valeur}ppm")
            recalibration(scd, valeur)
            systeme_actif = True
        except Exception as e:
            print("Erreur lors de la calibration:", e)
    
    elif ordre.startswith("ALERTE:"):
        try:
            systeme_actif = False
            valeur = int(float(ordre.split(":")[1]))
            print(f"Seuil alerte MAJ à : {valeur}ppm")
            
            SEUIL_CO2_OK = valeur
            with open("ini.txt", "w", encoding="utf-8") as ini:
                ini.write(f"{SEUIL_CO2_OK}\n")       
                ini.write(f"{SEUIL_CO2_ALERTE}\n")

            systeme_actif = True
        except Exception as e:
            print("Erreur lors de la MAJ du seuil alerte CO2:", e)
    
    elif ordre.startswith("ALARME:"):
        try:
            systeme_actif = False
            valeur = int(float(ordre.split(":")[1]))
            print(f"Seuil alarme MAJ à : {valeur}ppm")
            
            SEUIL_CO2_ALERTE = valeur

            with open("ini.txt", "w", encoding="utf-8") as ini:
                ini.write(f"{SEUIL_CO2_OK}\n")       
                ini.write(f"{SEUIL_CO2_ALERTE}\n")

            systeme_actif = True
        except Exception as e:
            print("Erreur lors de la MAJ du seuil alarme CO2:", e)
    
# ------------------ FONCTIONS PRINCIPALES ------------------ #

async def tache_leds_et_capteur(scd, strip, micro, wdt):
    while True:
        wdt.feed()  # On nourrit toujours le chien de garde
        
        if systeme_actif:
            try:
                # Mesure du son 
                bruit = niveau_sonore(micro)
                donnees_actuelles["bruit"] = bruit

                
                # Lecture CO2/températurehumidité dans le dictionnaire
                # obtenir_donnees() ne bloque pas le code grâce à capteur.data_ready
                mesure = obtenir_donnees(scd)
                if mesure:
                    co2, temp, hum = mesure
                    donnees_actuelles["co2"] = co2
                    donnees_actuelles["temp"] = round(temp, 1)
                    donnees_actuelles["humi"] = round(hum, 1)
                    
                    # MAJ de la couleur s'il n'y a pas de bruit
                    if bruit <= SEUIL_BRUIT_ALERTE:
                        indicateur_visuel(co2, strip, SEUIL_CO2_OK, SEUIL_CO2_ALERTE) 
                
                # Alerte sonore (découplé du CO2)
                if bruit > SEUIL_BRUIT_ALERTE:
                    print(f"Alerte Bruit détectée ! Niveau: {bruit}")
                    #  fait clignoter les LEDs 4 fois avec la couleur actuelle du CO2
                    for _ in range(4): 
                        if donnees_actuelles["co2"] > 0:
                            indicateur_visuel(donnees_actuelles["co2"], strip, SEUIL_CO2_OK, SEUIL_CO2_ALERTE)
                        await asyncio.sleep(0.1)
                        
                        piloter_led(0, strip) # Éteint
                        await asyncio.sleep(0.1)
                    
                    # retour à la couleur normale après clignotement
                    if donnees_actuelles["co2"] > 0:
                        indicateur_visuel(donnees_actuelles["co2"], strip, SEUIL_CO2_OK, SEUIL_CO2_ALERTE)

            except Exception as e:
                print("Erreur lecture capteur:", e)
        else:
            # Si le système est éteint
            piloter_led(0, strip) 
        await asyncio.sleep(0.1)

async def tache_mqtt(mqtt, wdt):
    # Indique client MQTT quelle fonction utiliser pour les messages reçus
    mqtt.set_callback(reception_message)
    while True:
        try:
            if mqtt.sock is None:
                print(f"Connexion au Broker...")
                if mqtt.connecter():
                    # S'abonne au topic de l'interrupteur (set_status)
                    mqtt.subscribe(f"ecole/{SALLE_ID}/set_status")
                    mqtt.publier(f"ecole/{SALLE_ID}/availability", "online", retain=True)
            
            if mqtt.sock:
                # Vérifie si Home Assistant a envoyé un message (ON ou OFF)
                mqtt.check_msg()
                
                # Envoie les stats que si le système est actif
                if systeme_actif and donnees_actuelles["co2"] > 0:
                    payload = ujson.dumps(donnees_actuelles)
                    mqtt.publier(f"ecole/{SALLE_ID}/state", payload) #
                    print(f"Données envoyées : {payload}")
                
        except Exception as e:
            print("Erreur MQTT:", e)

        for _ in range(INTERVALLE_MQTT):
            wdt.feed()
            await asyncio.sleep(1)


# --------------------- MAIN --------------------- #
async def main():
    global SEUIL_CO2_OK
    global SEUIL_CO2_ALERTE
    global scd
    wdt = WDT(timeout=8000) # Si le code freeze plus de 8s, la Pico reboot

    # init led
    strip = config_led(NUM_LEDS,PIN_DATA,PIN_CLOCK,BRIGHTNESS)

    # Init Son (Port A0 / ADC 26)
    micro = config_port_son(PIN_SON)
    
    # Init Capteur SCD avec Reset forcé pour éviter le "Working Mode"
    scd = config_port_scd(PIN_SDA, PIN_SCL, PORT_SCD)
    print("Réinitialisation du capteur")
    scd.stop_periodic_measurement()
    time.sleep(1)
    scd.start_periodic_measurement()
    print("Capteur SCD4x prêt !")
    
    # Init Réseau
    print(f"Initialisation Ethernet sur {IP_PICO}...")
    connecter_ethernet(IP_PICO, MAC_PICO)
    
    # Création du client MQTT avec les bons paramètres
    mqtt = MQTTClient(f"pico_{SALLE_ID}", BROKER_IP, 1883, MQTT_USER, MQTT_PASS, 
                      will_topic=f"ecole/{SALLE_ID}/availability") #will_topic sert de testament de connexion
    
# Set-up des seuils de CO2 par les dernieres valeurs de Home Assistant
    with open("ini.txt", "r", encoding="utf-8") as ini:
        seuils=ini.readlines() 
        print(seuils)
        SEUIL_CO2_OK=int(seuils[0])
        SEUIL_CO2_ALERTE=int(seuils[1])

    # Lancement du moteur asynchrone
    print(f"Système {SALLE_ID} opérationnel")
    await asyncio.gather(
        tache_leds_et_capteur(scd, strip, micro, wdt),
        tache_mqtt(mqtt, wdt)
    )

# Lancement global
try:
    asyncio.run(main())
except Exception as e:
    print("\n--- DETECTIVE ERREUR ---")
    # Cette ligne affiche le fichier et la ligne exacte
    sys.print_exception(e) 
    print("------------------------\n")

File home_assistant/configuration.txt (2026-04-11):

# Loads default set of integrations. Do not remove.
default_config:

# Load frontend themes from the themes folder
frontend:
  themes: !include_dir_merge_named themes

automation: !include automations.yaml
script: !include scripts.yaml
scene: !include scenes.yaml

mqtt:
  sensor:
    #sensor pour la salle 1
    - name: "CO2 Salle 1"
      unique_id: "pico_salle1_co2"
      state_topic: "ecole/salle1/state"
      value_template: "{{ value_json.co2 }}"
      unit_of_measurement: "ppm"
      device_class: "carbon_dioxide"
      state_class: "measurement"
      availability_topic: "ecole/salle1/availability"
      payload_available: "online"
      payload_not_available: "offline"

    - name: "Température Salle 1"
      unique_id: "pico_salle1_temp"
      state_topic: "ecole/salle1/state"
      value_template: "{{ value_json.temp }}"
      unit_of_measurement: "°C"
      device_class: "temperature"
      state_class: "measurement"
      availability_topic: "ecole/salle1/availability"
      payload_available: "online"
      payload_not_available: "offline"

    - name: "Bruit Salle 1"
      unique_id: "pico_salle1_bruit"
      state_topic: "ecole/salle1/state"
      value_template: "{{ value_json.bruit }}"
      unit_of_measurement: "pts"
      state_class: "measurement"
      availability_topic: "ecole/salle1/availability"
      payload_available: "online"
      payload_not_available: "offline"

    - name: "Humidité Salle 1"
      unique_id: "pico_salle1_humi"
      state_topic: "ecole/salle1/state"
      value_template: "{{ value_json.humi }}"
      unit_of_measurement: "%"
      device_class: "humidity"
      state_class: "measurement"
      availability_topic: "ecole/salle1/availability"
      payload_available: "online"
      payload_not_available: "offline"

      #sensor pour la salle 2
    - name: "CO2 Salle 2"
      unique_id: "pico_salle2_co2"
      state_topic: "ecole/salle2/state"
      value_template: "{{ value_json.co2 }}"
      unit_of_measurement: "ppm"
      device_class: "carbon_dioxide"
      state_class: "measurement"
      availability_topic: "ecole/salle2/availability"
      payload_available: "online"
      payload_not_available: "offline"

    - name: "Température Salle 2"
      unique_id: "pico_salle2_temp"
      state_topic: "ecole/salle2/state"
      value_template: "{{ value_json.temp }}"
      unit_of_measurement: "°C"
      device_class: "temperature"
      state_class: "measurement"
      availability_topic: "ecole/salle2/availability"
      payload_available: "online"
      payload_not_available: "offline"

    - name: "Bruit Salle 2"
      unique_id: "pico_salle2_bruit"
      state_topic: "ecole/salle2/state"
      value_template: "{{ value_json.bruit }}"
      unit_of_measurement: "pts"
      state_class: "measurement"
      availability_topic: "ecole/salle2/availability"
      payload_available: "online"
      payload_not_available: "offline"

    - name: "Humidité Salle 2"
      unique_id: "pico_salle2_humi"
      state_topic: "ecole/salle2/state"
      value_template: "{{ value_json.humi }}"
      unit_of_measurement: "%"
      device_class: "humidity"
      state_class: "measurement"
      availability_topic: "ecole/salle2/availability"
      payload_available: "online"
      payload_not_available: "offline"

  switch:
    #interrupteur locale pour chaque salle
    - name: "Activation Salle 1"
      unique_id: "pico_salle1_activation"
      state_topic: "ecole/salle1/status"
      command_topic: "ecole/salle1/set_status"
      payload_on: "ON"
      payload_off: "OFF"
      optimistic: true
      retain: true

    - name: "Activation Salle 2"
      unique_id: "pico_salle2_activation"
      state_topic: "ecole/salle2/status"
      command_topic: "ecole/salle2/set_status"
      payload_on: "ON"
      payload_off: "OFF"
      optimistic: true
      retain: true
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

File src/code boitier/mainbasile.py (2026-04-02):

import uasyncio as asyncio
import ujson
from machine import WDT, Pin
import sys
import time

# 1. Dossier des librairies
sys.path.append('/src/code boitier')

from lib_scd4x import config_port_scd, obtenir_donnees
from lib_led import config_led, indicateur_visuel
from lib_mqtt import MQTTClient, connecter_ethernet

# --- CONFIGURATION (Copiée de ton test_mqtt qui marche) ---
SALLE_ID = "salle1"
IP_PICO = "10.40.1.22"
BROKER_IP = "10.40.1.20"
MQTT_USER = "reseau_co2"      # Minuscule comme dans ton test
MQTT_PASS = "co2_saintpaul"  # Ton mot de passe qui fonctionne
INTERVALLE_MQTT = 30         # Envoi toutes les 30 secondes pour commencer

# Variables globales pour partager les données entre les tâches
donnees_actuelles = {"co2": 400, "temp": 20.0, "humi": 50.0}

async def envoyer_configuration_ha(mqtt):
    """ Envoie la configuration pour que HA crée le capteur automatiquement """
    config_topic = f"homeassistant/sensor/{SALLE_ID}_co2/config"
    payload = {
        "name": f"CO2 {SALLE_ID}",
        "state_topic": f"ecole/{SALLE_ID}/state",
        "unit_of_measurement": "ppm",
        "value_template": "{{ value_json.co2 }}",
        "device_class": "carbon_dioxide",
        "unique_id": f"pico_{SALLE_ID}_co2",
        "availability_topic": f"ecole/{SALLE_ID}/availability"
    }
    mqtt.publier(config_topic, ujson.dumps(payload), retain=True)
    print("Configuration Discovery envoyée à Home Assistant")

async def tache_leds_et_capteur(scd, strip, wdt):
    """ Tâche rapide : mise à jour visuelle toutes les 5 secondes """
    while True:
        wdt.feed()  # On rassure le watchdog
        try:
            mesure = obtenir_donnees(scd)
            if mesure:
                co2, temp, hum = mesure
                donnees_actuelles["co2"] = co2
                donnees_actuelles["temp"] = round(temp, 1)
                donnees_actuelles["humi"] = round(hum, 1)
                
                # Mise à jour des LEDs physiques
                indicateur_visuel(co2, strip)
        except Exception as e:
            print("Erreur lecture capteur:", e)
            
        await asyncio.sleep(5)

async def tache_mqtt(mqtt, wdt):
    """ Tâche lente : communication avec Home Assistant """
    configuration_envoyee = False
    
    while True:
        try:
            # Vérification de la connexion
            if mqtt.sock is None:
                print(f"Tentative de connexion au Broker {BROKER_IP}...")
                if mqtt.connecter():
                    print("✅ CONNECTÉ à Home Assistant !")
                    mqtt.publier(f"ecole/{SALLE_ID}/availability", "online", retain=True)
                    
                    if not configuration_envoyee:
                        await envoyer_configuration_ha(mqtt)
                        configuration_envoyee = True
            
            # Envoi des données réelles du capteur
            if mqtt.sock:
                payload = ujson.dumps(donnees_actuelles)
                mqtt.publier(f"ecole/{SALLE_ID}/state", payload)
                print(f"🚀 Données envoyées : {payload}")
                
        except Exception as e:
            print("Erreur MQTT:", e)
            configuration_envoyee = False 

        # Attente découpée pour ne pas faire rebooter le watchdog
        for _ in range(INTERVALLE_MQTT):
            wdt.feed()
            await asyncio.sleep(1)

async def main():
    # 1. Matériel et Sécurité
    wdt = WDT(timeout=8000) # Si le code freeze plus de 8s, la Pico reboot
    strip, _ = config_led()
    
    # Init Capteur avec Reset forcé pour éviter le "Working Mode"
    scd = config_port_scd(pin_sda=6, pin_scl=7, port=1)
    print("Réinitialisation du capteur...")
    scd.stop_periodic_measurement()
    time.sleep(1)
    scd.start_periodic_measurement()
    print("Capteur SCD4x prêt !")
    
    # 2. Réseau
    print(f"Initialisation Ethernet sur {IP_PICO}...")
    connecter_ethernet(IP_PICO, "DE:AD:BE:EF:00:01")
    
    # Création du client MQTT avec les bons paramètres de ton test
    mqtt = MQTTClient(f"pico_{SALLE_ID}", BROKER_IP, 1883, MQTT_USER, MQTT_PASS, 
                      will_topic=f"ecole/{SALLE_ID}/availability")

    # 3. Lancement du moteur asynchrone
    print(f"Système {SALLE_ID} opérationnel")
    await asyncio.gather(
        tache_leds_et_capteur(scd, strip, wdt),
        tache_mqtt(mqtt, wdt)
    )

# Lancement global
try:
    asyncio.run(main())
except Exception as e:
    print("Crash système fatal:", e)

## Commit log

2025-12-03 reorganisation des dossiers
2025-12-05 1ere entrée en contact avec i2c
2026-02-06 réecriture des fichiers pour inclure les fonctions principales utilisées & mise en ordre du fichier main
2026-02-14 fichier crée pour obtenir les adresses MAC
2026-04-02 passage de esphome à MQTT, création lib_mqtt
2026-04-02 premier dialogue avec HA et test SCD
    [UCP_moustache1.3mf, moustache1.blend, moustache1.stl]
2026-04-04 HA et communiquation réussi
    [configuration yaml.txt]
2026-04-06 communication recto-verso
    [configuration yaml.txt]
2026-04-13 guide de fabrication v1
2026-05-06 regroupement des codes et des fichiers d'impression
    [CASQUETTE_CREUSE.stl, LOUTRE_CREUSEE_VF.stl, LOUTRE_TROUEE_0.7mm.stl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]
2026-05-18 amélioration des commentaires
2026-05-18 amélioration des commentaires du main
2026-05-19 ajout de commentaires dans le main
2026-05-19 ajout feuille de route
2026-05-20 ajout rapport de projet
